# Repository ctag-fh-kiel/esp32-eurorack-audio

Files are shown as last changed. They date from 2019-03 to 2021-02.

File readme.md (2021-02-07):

# ESP32 Eurorack Audio Synthesis Module
Hardware for Strämpler

## What it is
Base board (design with KiCad) for using the ESP32 WROVER module in the context of real-time audio applications for eurorack synthesizer setups.

## Errata
CV in 1+2 are -1.5V .. 5.5V

## License
Licensed under CC BY-NC-SA 4.0
https://creativecommons.org/licenses/by-nc-sa/4.0/
(C) Robert Manzke 2019

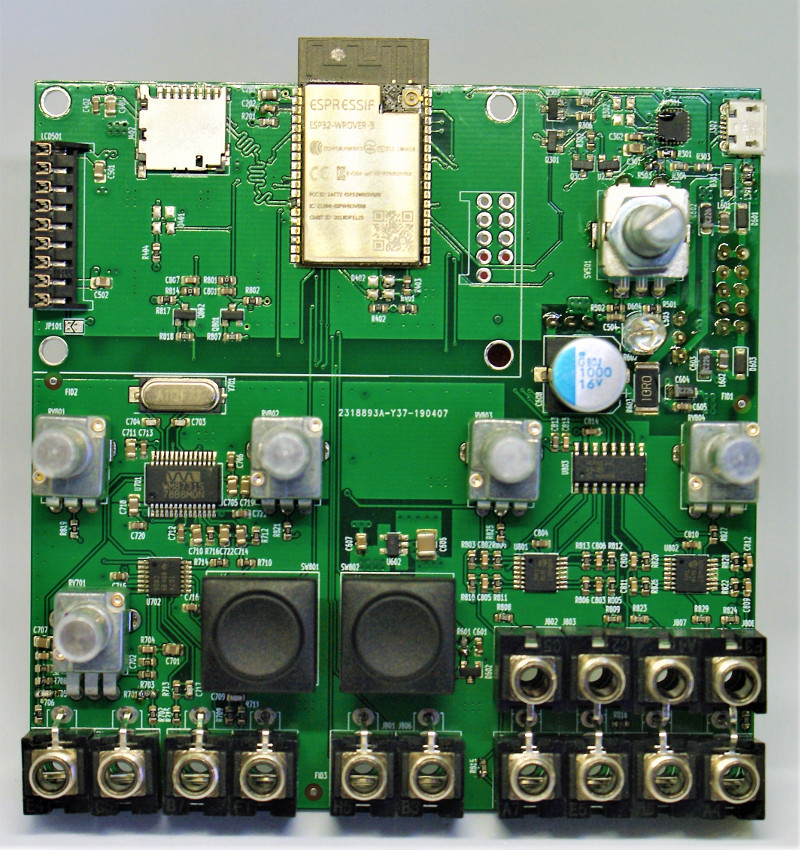
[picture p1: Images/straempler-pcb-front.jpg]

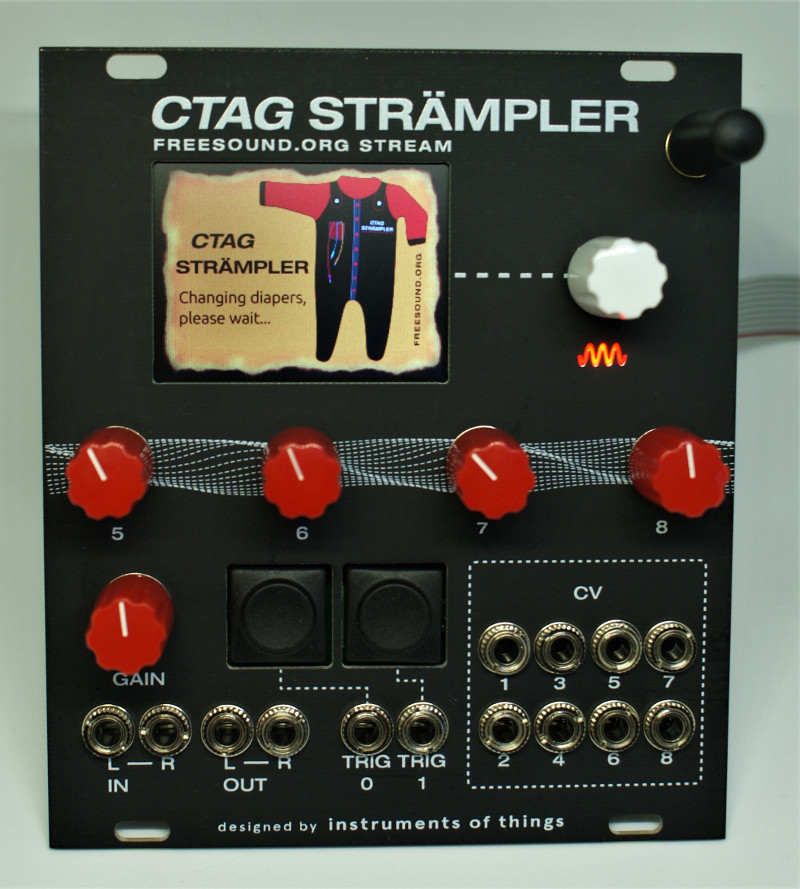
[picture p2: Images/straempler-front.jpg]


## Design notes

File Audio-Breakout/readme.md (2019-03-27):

# Stereo line IO + headphones breakout board for ESP32 Eurorack Audio Synthesis Module

Licensed under CC BY-NC-SA 4.0
https://creativecommons.org/licenses/by-nc-sa/4.0/
(C) Robert Manzke 2019

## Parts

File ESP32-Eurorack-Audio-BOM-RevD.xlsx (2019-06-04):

Designator | Package | Quantity | Designation | Mouser | Remarks
LCD501 | TFT_2.2 | 1 | TFT_ILI9341 | MDF7-9S-2.54DSA(55) |  | https://www.aliexpress.com/item/Smart-Electronics-2-2-Inch-240-320-Dots-SPI-TFT-LCD-Serial-Port-Module-Display-ILI9341/32607741715.html
C505,C504,C503,C813,C302,C402,C601,C605,C706,C712,C715,C716,C720,C721,C801,C804,C807,C810,C713 | C_0603_1608Metric | 19 | 100n | 81-GRM033C71C104KE4J (https://www.mouser.de/ProductDetail/Murata-Electronics/GRM033C71C104KE14J)
U301 | QFN-24-1EP_4x4mm_P0.5mm_EP2.6x2.6mm | 1 | CP2102N-A01-GQFN24 | 634-CP2102NA01GQFN24
D604 | LED_D5.0mm_Clear | 1 | ~ | 743-INL-5AR30 (https://www.mouser.de/QuickViewProdDetail.aspx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) |  | Larger angle and intensity: | 941-C5SMFRJECT0W0BB2
U202 | SOT-23 | 1 | MIC803 | 998-MIC803-31D3VM3TR
U601 | SIP3_11.6x8.5mm | 1 | R-78E3.3-1.0 | 919-R-78E3.3-1.0
R603 | R_2512_6332Metric | 1 | 10 | 279-CRGP2512F10R
C608 | CP_Elec_10x12.6 | 1 | 1000u | 661-APXG160A102MJA0G
C815,C202,C814 | C_0603_1608Metric | 3 | 1u | 603-CC603KRX7R7BB105 | X7R
U201 | ESP32-WROVER | 1 | ESP32-WROVER | 356-ESP32WROIB(16MB) |  | Important use WROVER-B the non-B has boot issues |  |  | For IPEX use e.g. this antenna | https://de.aliexpress.com/item/1pcs-2-4Ghz-Antenna-SMA-male-3dbi-Zigbee-wifi-antenna-mini-short-rubber-aerial-SMA/32813612333.html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
C201,C401,C501,C607,C701,C705,C707,C710,C714,C718,C719,C722,C502,C301,C711 | C_0805_2012Metric | 15 | 10u | 81-GRM21BR70J106KA3L (https://www.mouser.de/ProductDetail/Murata-Electronics/GRM21BR70J106KA73L) | X7R
C602,C603,C604 | CP_EIA-3216-12_Kemet-S | 3 | 22u | 647-F931C226MAA (https://www.mouser.de/ProductDetail/AVX/F951C226KQAAQ2)
C702,C708 | C_0603_1608Metric | 2 | 220p | 710-885012206055 (https://www.mouser.de/ProductDetail/Wurth-Electronics/885012206055)
C703,C704,C709,C717 | C_0603_1608Metric | 4 | 18p | 80-C0603C180J5G
C802,C803,C805,C806,C808,C809,C811,C812 | C_0603_1608Metric | 8 | 1n | 77-VJ0603Y102KXQCBC (https://www.mouser.de/ProductDetail/Vishay-Vitramon/VJ0603Y102KXQCW1BC)
D601,D603 | D_SOD-123 | 2 | STPS2L40ZFY | 511-STPS2L40ZFY
D602 | SOT-23 | 1 | LM4040B-10 | 595-LM4040B10IDBZR (https://www.mouser.de/ProductDetail/Texas-Instruments/LM4040B10IDBZR)
J302 | USB_Micro-B_Molex-105017-0001 | 1 | USB_B_Micro | 105017-0001 (https://www.mouser.de/ProductDetail/Molex/105017-0001)
J402 | microSD_HC_Hirose_DM3D-SF | 1 | Micro_SD_Card | 798-DM3D-SF (https://www.mouser.de/ProductDetail/Hirose-Connector/DM3D-SF)
J601 | PinHeader_2x05_P2.54mm_Vertical | 1 | PWR |  | Standard 2,54mm
J702 | THONKICONN | 1 | RIN |  | PJ398SM | https://www.thonk.co.uk/shop/thonkiconn/
J703 | THONKICONN | 1 | LIN/MONO |  | PJ398SM | https://www.thonk.co.uk/shop/thonkiconn/
J704 | THONKICONN | 1 | ROUT |  | PJ398SM | https://www.thonk.co.uk/shop/thonkiconn/
J705 | THONKICONN | 1 | LOUT |  | PJ398SM | https://www.thonk.co.uk/shop/thonkiconn/
J801 | THONKICONN | 1 | TRG0 |  | PJ398SM | https://www.thonk.co.uk/shop/thonkiconn/
J802 | THONKICONN | 1 | CVIN1 |  | PJ398SM | https://www.thonk.co.uk/shop/thonkiconn/
J803 | THONKICONN | 1 | CVIN3 |  | PJ398SM | https://www.thonk.co.uk/shop/thonkiconn/
J804 | THONKICONN | 1 | CVIN2 |  | PJ398SM | https://www.thonk.co.uk/shop/thonkiconn/
J805,J807 | THONKICONN | 2 | CVIN4 |  | PJ398SM | https://www.thonk.co.uk/shop/thonkiconn/
J806 | THONKICONN | 1 | TRG1 |  | PJ398SM | https://www.thonk.co.uk/shop/thonkiconn/
J808 | THONKICONN | 1 | CVIN5 |  | PJ398SM | https://www.thonk.co.uk/shop/thonkiconn/
J809 | THONKICONN | 1 | CVIN6 |  | PJ398SM | https://www.thonk.co.uk/shop/thonkiconn/
J810 | THONKICONN | 1 | CVIN7 |  | PJ398SM | https://www.thonk.co.uk/shop/thonkiconn/
L601,L602 | C_0805_2012Metric | 2 | 600 | 623-2508056017Y2
Q301,Q302,Q303,Q801,Q802 | SOT-23 | 5 | SS8050-G | 750-SS8050-G
RV701 | Alpha_9mm_stereo | 1 | 50k audio |  | VERTICAL - DUAL GANG/STEREO: A50K - 50K Audio | https://www.thonk.co.uk/shop/alpha-9mm-pots/
RV801,RV802,RV803,RV804 | Alpha_9mm | 4 | 10k lin |  | VERTICAL: B10K - 10K Linear | https://www.thonk.co.uk/shop/thonkiconn/
SW501 | RotaryEncoder_Alps_EC11E-Switch_Vertical_H20mm | 1 | SEL |  |  | https://www.aliexpress.com/item/10pcs-Rotary-encoder-code-switch-EC11-audio-digital-potentiometer-with-switch-5Pin-handle-length-20mm-WAVGAT/32839106848.html
SW801 | SW_6425 | 1 | TRG0 | 979-6425.0101 | Cap | 979-826.000.071 | Or black | 826000011
SW802 | SW_6425 | 1 | TRG1 | 979-6425.0101 | Cap | 979-826.000.071 |  | 826000011
U602 | TSOT-23-5 | 1 | ADP7118 | 584-ADP7118AUJZ3.3R7
U701 | SSOP-28_5.3x10.2mm_P0.65mm | 1 | WM8731 | 238-WM8731SEDS/V (https://www.mouser.de/ProductDetail/Cirrus-Logic/WM8731SEDS-V?qs=sGAEpiMZZMthNezIpKscMWquczdXLZMI)
U702 | TSSOP-14_4.4x5mm_P0.65mm | 1 | TL074 | 595-TL074CPWR (https://www.mouser.de/ProductDetail/Texas-Instruments/TL074CPWR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)
U801,U802 | TSSOP-14_4.4x5mm_P0.65mm | 2 | MCP6004 | 579-MCP6004-I/ST (https://www.mouser.de/ProductDetail/Microchip-Technology/MCP6004-I-ST)
U803 | SOIC-16_3.9x9.9mm_P1.27mm | 1 | MCP3208 | 579-MCP3208T-CI/SL (https://www.mouser.de/ProductDetail/Microchip-Technology/MCP3208T-CI-SL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)
Y701 | Crystal_SMD_HC49-SD | 1 | 11.289600MHz | 815-ABLS211.2896B4YT (https://www.mouser.de/ProductDetail/ABRACON/ABLS2-112896MHz-B4Y-T)
R201,R301,R305,R306,R401,R402,R403,R404,R501,R502,R503,R802,R817,R302 | R_0603_1608Metric | 14 | 10k | 652-CR0603FX-1002ELF | 1%
R303 | R_0603_1608Metric | 1 | 22.1k | 652-CR0603FX-2212ELF (https://www.mouser.de/ProductDetail/Bourns/CR0603-FX-2212ELF) | 1%
R304 | R_0603_1608Metric | 1 | 47.5k | 603-RC0603FR-0747K5L (https://www.mouser.de/ProductDetail/Yageo/RC0603FR-0747K5L) | 1%
R601 | R_0603_1608Metric | 1 | 220 | 652-CR0603FX-2200ELF | 1%
R602 | R_0805_2012Metric | 1 | 68 | 603-AC0603FR-0768RL | 1%
R701,R705 | R_0603_1608Metric | 2 | 3k3 | 652-CR0603-FX3301ELF | 1%
R702,R706 | R_0603_1608Metric | 2 | 22k | 652-CR0603FX-2202ELF | 1%
R703,R704,R707,R708,R710,R714 | R_0603_1608Metric | 6 | 5k6 | 652-CR0603FX-5601ELF | 1%
R709,R712,R713,R716 | R_0603_1608Metric | 4 | 39k | 652-CR0603FX-3902ELF | 1%
R711,R715 | R_0603_1608Metric | 2 | 1k | 652-CR0603FX-1001ELF | 1%
R803,R810 | R_0603_1608Metric | 2 | 180k | 652-CR0603FX-1803ELF | 1%
R804,R811 | R_0603_1608Metric | 2 | 47k | 652-CR0603FX-4702ELF (https://www.mouser.de/ProductDetail/Bourns/CR0603-FX-4702ELF) | 1%
R805,R812,R819,R821,R825,R827 | R_0603_1608Metric | 6 | 200k | 652-CR0603FX-2003ELF | 1%
R806,R813 | R_0603_1608Metric | 2 | 33k | 652-CR0603FX-3302ELF | 1%
R807,R808,R809,R815,R816,R818,R823,R824,R829,R830 | R_0603_1608Metric | 10 | 100k | 603-RC0603FR-07100KL (https://www.mouser.de/ProductDetail/Yageo/RC0603FR-07100KL) | 1%
R820,R822,R826,R828 | R_0603_1608Metric | 4 | 66.5k | 652-CR0603-FX6652ELF | 1%
J701 | PinHeader_2x05_P2.54mm_Vertical_SMD | 1 | AUEXT |  | Standard 2,54mm SMD
C606 | C_1210_3225Metric | 1 | 10u | 710-885012209005 | X7R 16V
TP101 | TestPoint_Keystone_5019_Minature | 1 | TP_IO19 | 534-5019

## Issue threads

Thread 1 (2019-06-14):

R704 und C702 designators swapped in top silkscreen rev-c2

ctag-fh-kiel, 2019-06-14:
Fixed in rev-d

Closed 2019-06-14.

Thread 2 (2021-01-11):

What kind of esp32-wrover specific in this project?

colesnicov, 2021-01-11:
Good day. I want to ask **what kind of esp32-wrover specific in this project**? There are a lot of them, and I don't know much about them, so I don't want to make a mistake, I'd rather ask. **Which ones are guaranteed to work for me here?** [Here (_mouser_)](https://eu.mouser.com/Search/Refine?Keyword=ESP32-WROVER) I found **esp32-wrover**, **esp32-wrover-e**, **esp32-wrover-i**, **esp32-wrover-ie**, **esp32-wrover-b**, **esp32-wrover-ib**... Thank you for your help.

ctag-fh-kiel, 2021-01-11:
You need a wrover with 16MB flash and at least 4 MB SPI RAM, it depends if you want external antenna, if so, chose WROVER with IPEX connector.
Component details are here https://github.com/ctag-fh-kiel/ctag-tbd/tree/master/hw/pcb in the bom.xlsx spreadsheet.
esp32-wrover-ie is the newest one, should work well too. In the bom is esp32-wrover-ib

colesnicov, 2021-01-12:
Thank you.

colesnicov, 2021-01-12:
Hi. I'm sorry, but I'm here again. I'm looking at the BOM file you wrote me the link above, and at the same time I have a project open in the kicad from the address https://github.com/ctag-fh-kiel/esp32-eurorack-audio. And I see here that the components that are listed in the BOM file are missing here in the project. Can you please explain to me which project it is, sw, hw, bom? It seems to me you have it scattered over different folders + duplication..  :-/

**It should be stated in the BOM: C508, C507, C503, C506, C505 = 4.7uF but in the project C505 = 100nF (not 4.7uF !!) and C503, C506, C507, C508 are missing** in the project. It can't work like this ..

colesnicov, 2021-01-12:
Or one more time. These are two different projects, but do they use the same esp32-wrover module? HMM, I'm confused. Correctly?

colesnicov, 2021-01-12:
I've got it. I'm sorry :)

ctag-fh-kiel, 2021-01-12:
No problem ;) The project is pretty well structured. Everything regarding hardware is in the hw folder. All other folders are relevant for SW (firmware + simulator).
hw/frontplate are gerbers for a frontplate design.
hw/pcb are all KiCad and gerbers for the hardware.
Note that the current design uses QFNs + 0402s which are very advanced for handsoldering.
Let me know if you spot any errors in the bom.xlsx file, I will try to fix and am grateful for help sorting out issues.

colesnicov, 2021-01-12:
No no, we probably don't understand each other. I want to build for a friend [this CTAG Strämpler](https://github.com/ctag-fh-kiel/ctag-straempler)

I went through your repository and I understood it like this:
https://github.com/ctag-fh-kiel/esp32-eurorack-audio is hardware
https://github.com/ctag-fh-kiel/ctag-straempler is software
https://github.com/ctag-fh-kiel/ctag-tbd is something else (add-on module) ...

It's right?

ctag-fh-kiel, 2021-01-12:
Ah, got you, sorry, I was at the TBD ;)
Yes, you are right! Sorry for the confusion.
Forget my previous comment...

ctag-fh-kiel, 2021-01-12:
BOM is here https://github.com/ctag-fh-kiel/esp32-eurorack-audio/blob/rev-d/ESP32-Eurorack-Audio-BOM-RevD.xlsx

colesnicov, 2021-01-12:
No problem. Thank you for your help ;)

colesnicov, 2021-01-13:
Hi. I'm bothering again :) I can't opt for some of the ESP32-wrover module. There is a note in the BOM file that I have to use 'WROVER-B' otherwise non-B has problems booting. Could you please tell me which of the modules I should buy here is the [link to the mouser](https://cz.mouser.com/Espressif/WiFi-Modules-80211/ESP32-WROVER-Series/_/N-1y98oj6Z6l7qaZ1y94wm8)? I did not find a version with 16 MB but there are others. I'm a dick. I don't work much with ESP, so I can't decide.

ctag-fh-kiel, 2021-01-13:
You can use this one ESP32-WROVER-IE, ESP32-D0WD-V3, 3.3V 64Mbit PSRAM, 16 MB SPI flash, IPEX connector:
https://www.mouser.de/ProductDetail/Espressif-Systems/ESP32-WROVER-IEM213EH2864UH3Q0/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

colesnicov, 2021-01-14:
OK. I'll try. Thank you for the recommendation.

Closed 2021-01-12.

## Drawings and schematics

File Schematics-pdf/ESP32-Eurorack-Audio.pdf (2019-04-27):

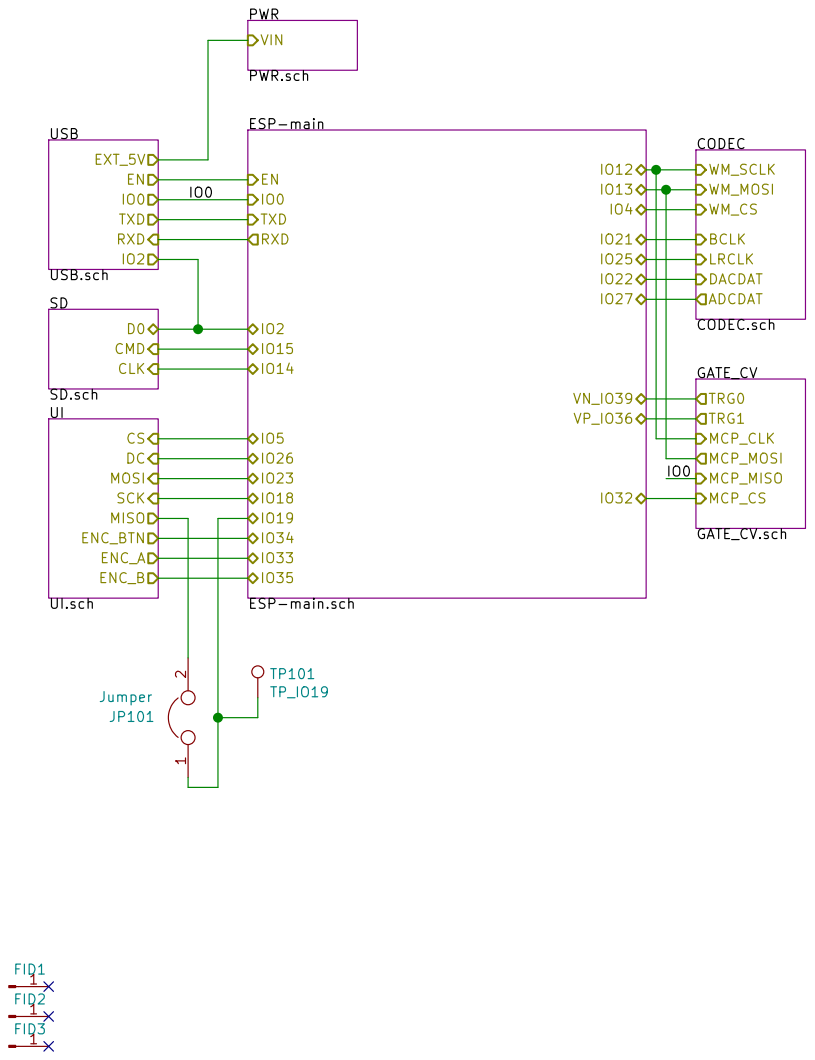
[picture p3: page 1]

PWR
PWR.sch VIN
ESP-main ESP-main.sch TXD

https://creativecommons.org/licenses/by-nc-sa/4.0/ Licensed under CC BY-NC-SA 4.0

File: ESP32-Eurorack-Audio.sch Sheet: / (c) Robert Manzke 2019

Id: 1/8 Title: ESP32 Eurorack Audio Module

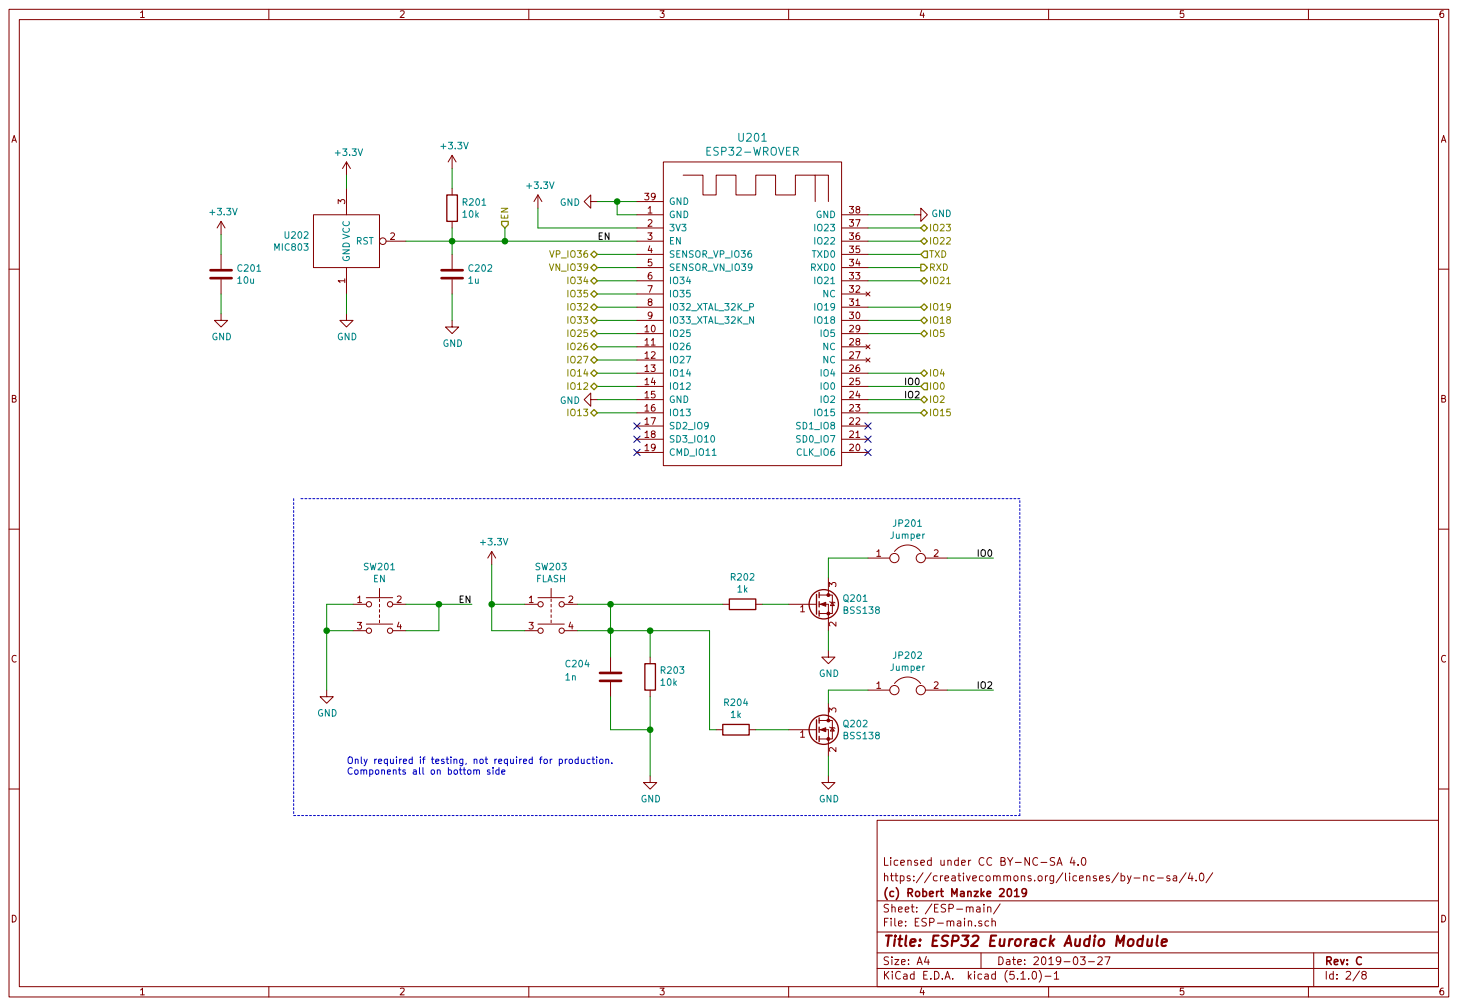
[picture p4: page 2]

+3.3V GND
Components all on bottom side GND
1u GND

Only required if testing, not required for production.

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

File: ESP-main.sch Sheet: /ESP-main/ (c) Robert Manzke 2019

Id: 2/8 Title: ESP32 Eurorack Audio Module

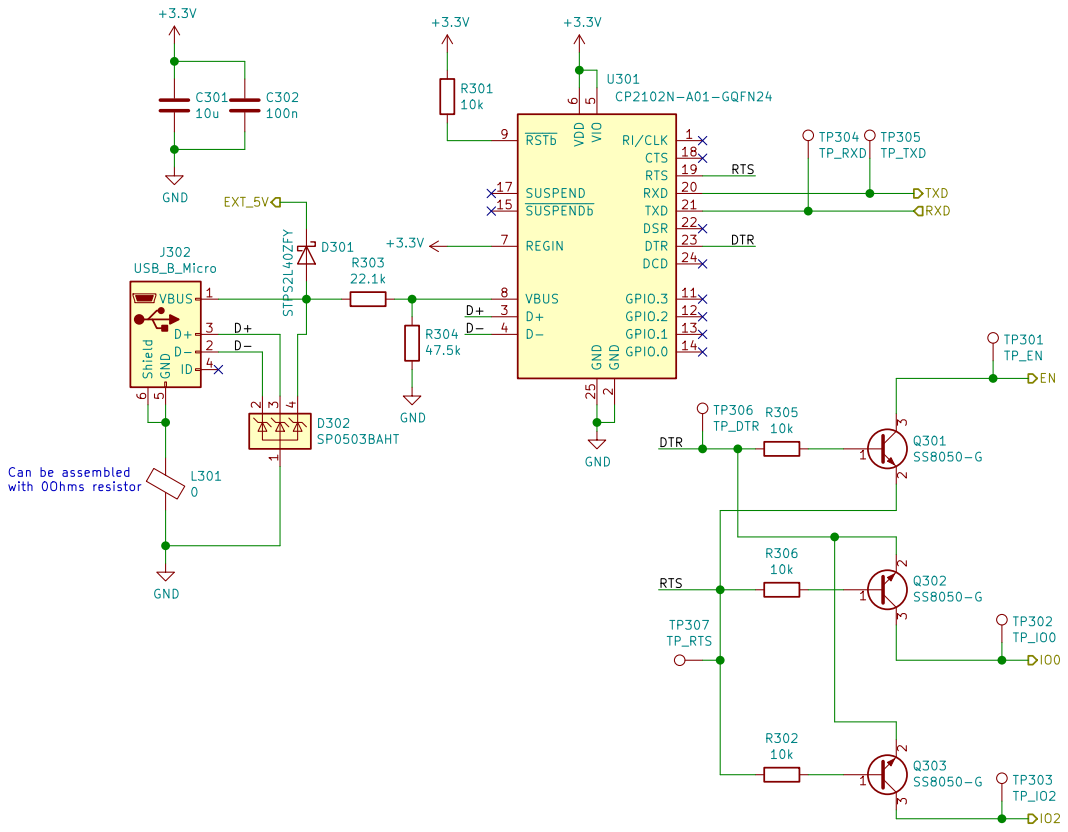
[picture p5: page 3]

2 RXD 20 TXD 21 DSR 22 DTR 23 DCD 24 GND 25 D+ 3 D- 4 VIO

Can be assembled with 0Ohms resistor

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

File: USB.sch Sheet: /USB/ (c) Robert Manzke 2019

Id: 3/8 Title: ESP32 Eurorack Audio Module

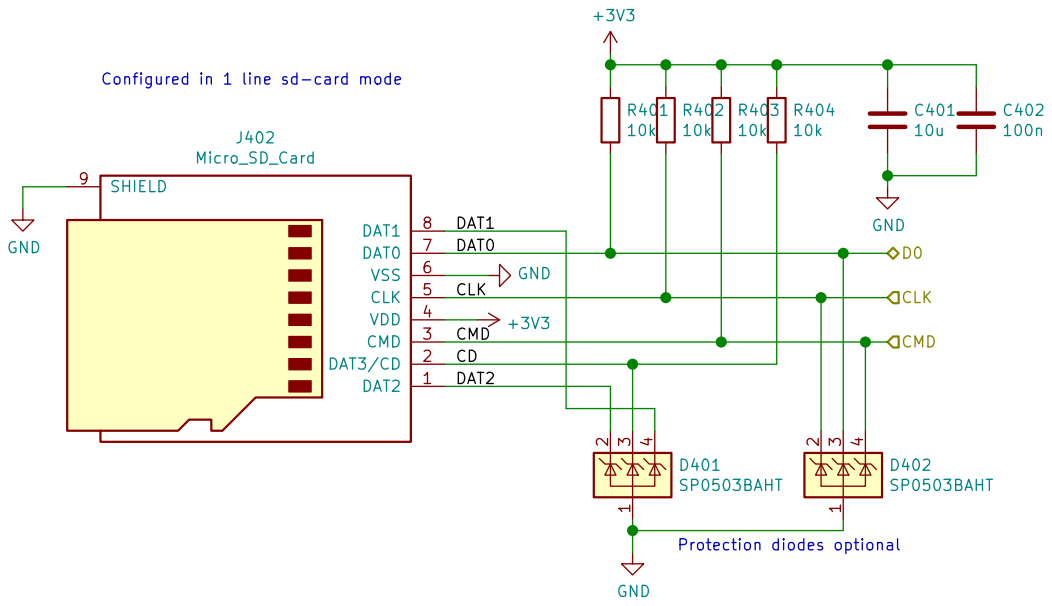
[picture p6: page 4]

DAT2 Configured in 1 line sd-card mode

+3V3 GND

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

File: SD.sch Sheet: /SD/ (c) Robert Manzke 2019

Id: 4/8 Title: ESP32 Eurorack Audio Module

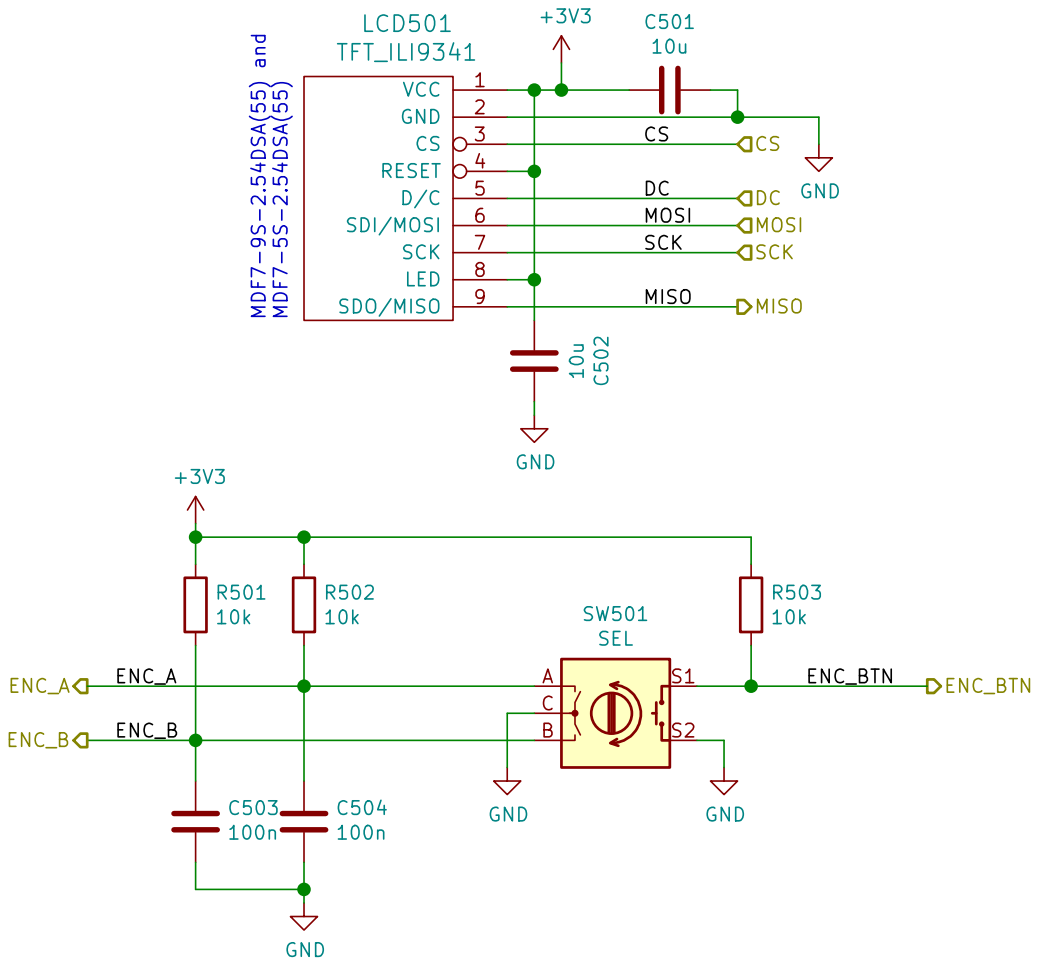
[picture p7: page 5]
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

File: UI.sch Sheet: /UI/ (c) Robert Manzke 2019

Id: 5/8 Title: ESP32 Eurorack Audio Module

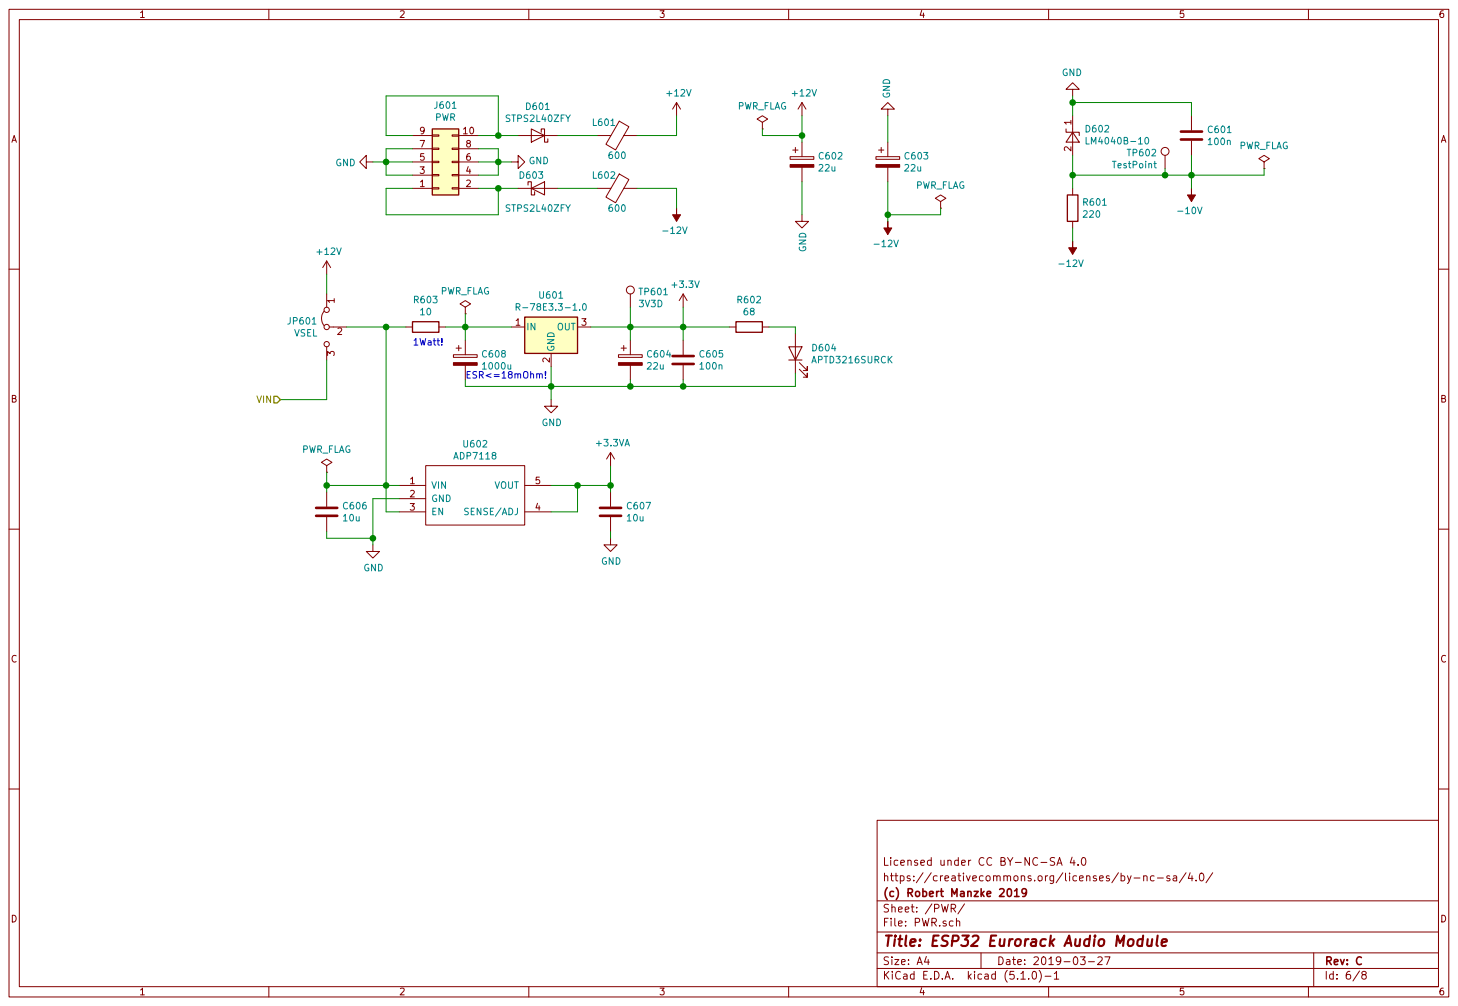
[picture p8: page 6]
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

File: PWR.sch Sheet: /PWR/ (c) Robert Manzke 2019

Id: 6/8 Title: ESP32 Eurorack Audio Module

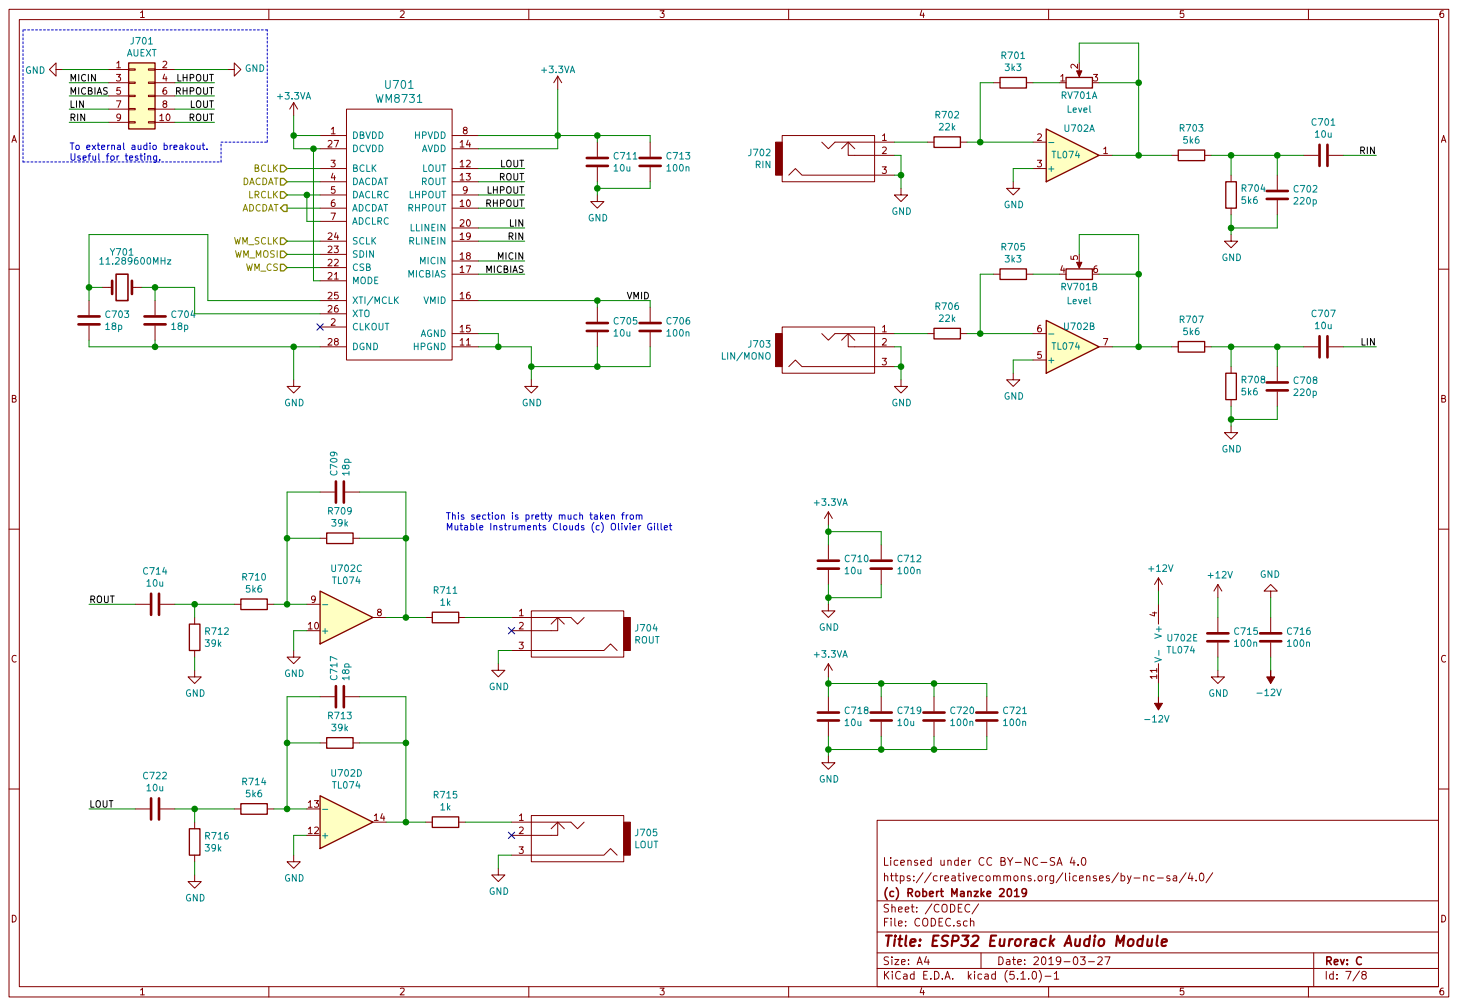
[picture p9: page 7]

Mutable Instruments Clouds (c) Olivier Gillet To external audio breakout. Useful for testing.

This section is pretty much taken from

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

File: CODEC.sch Sheet: /CODEC/ (c) Robert Manzke 2019

Id: 7/8 Title: ESP32 Eurorack Audio Module

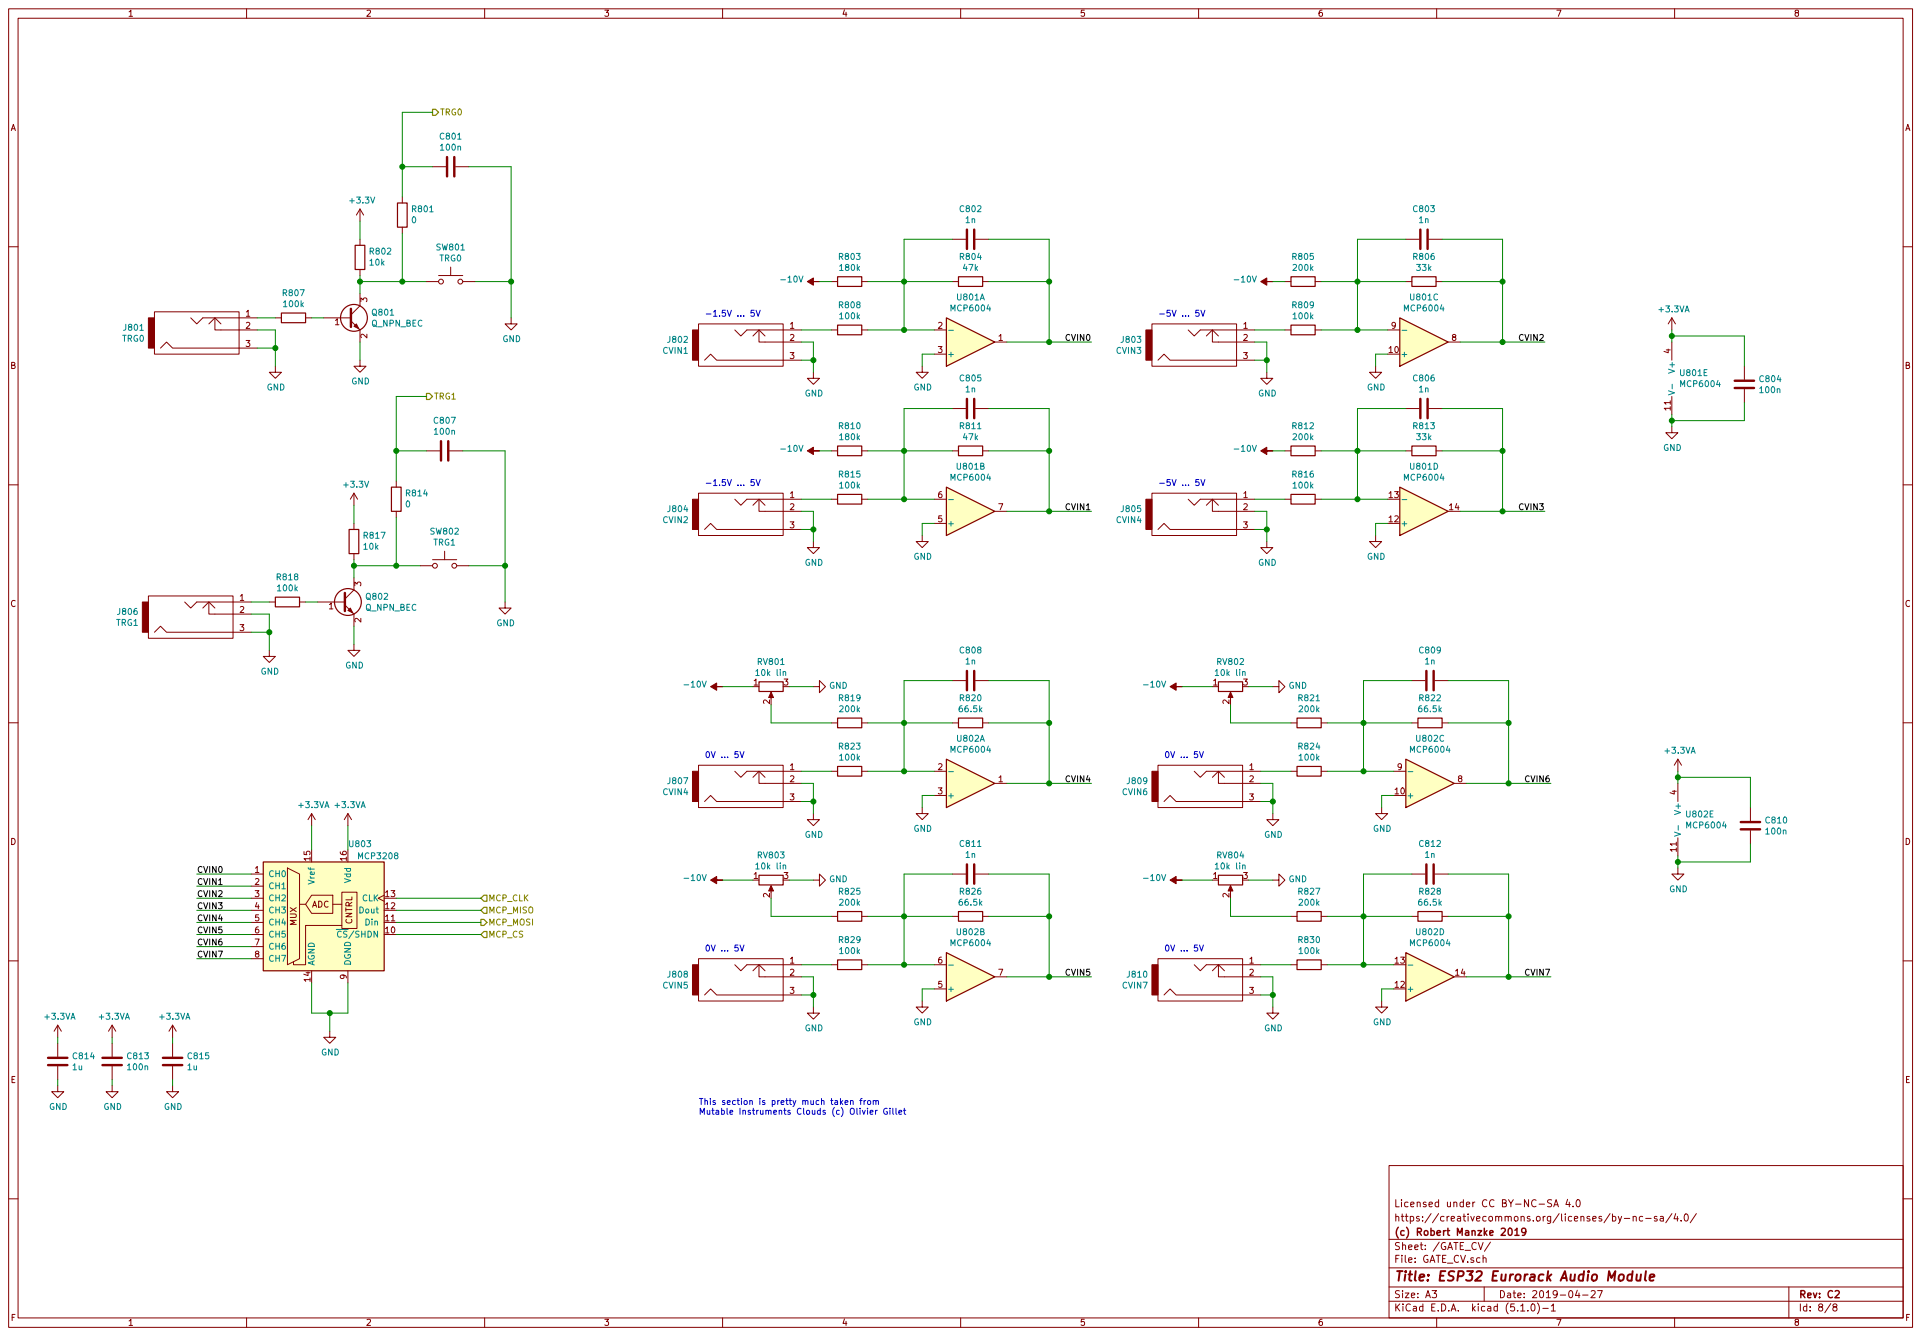
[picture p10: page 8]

This section is pretty much taken from
Mutable Instruments Clouds (c) Olivier Gillet

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

(c) Robert Manzke 2019
Sheet: /GATE_CV/
File: GATE_CV.sch
Id: 8/8 Title: ESP32 Eurorack Audio Module

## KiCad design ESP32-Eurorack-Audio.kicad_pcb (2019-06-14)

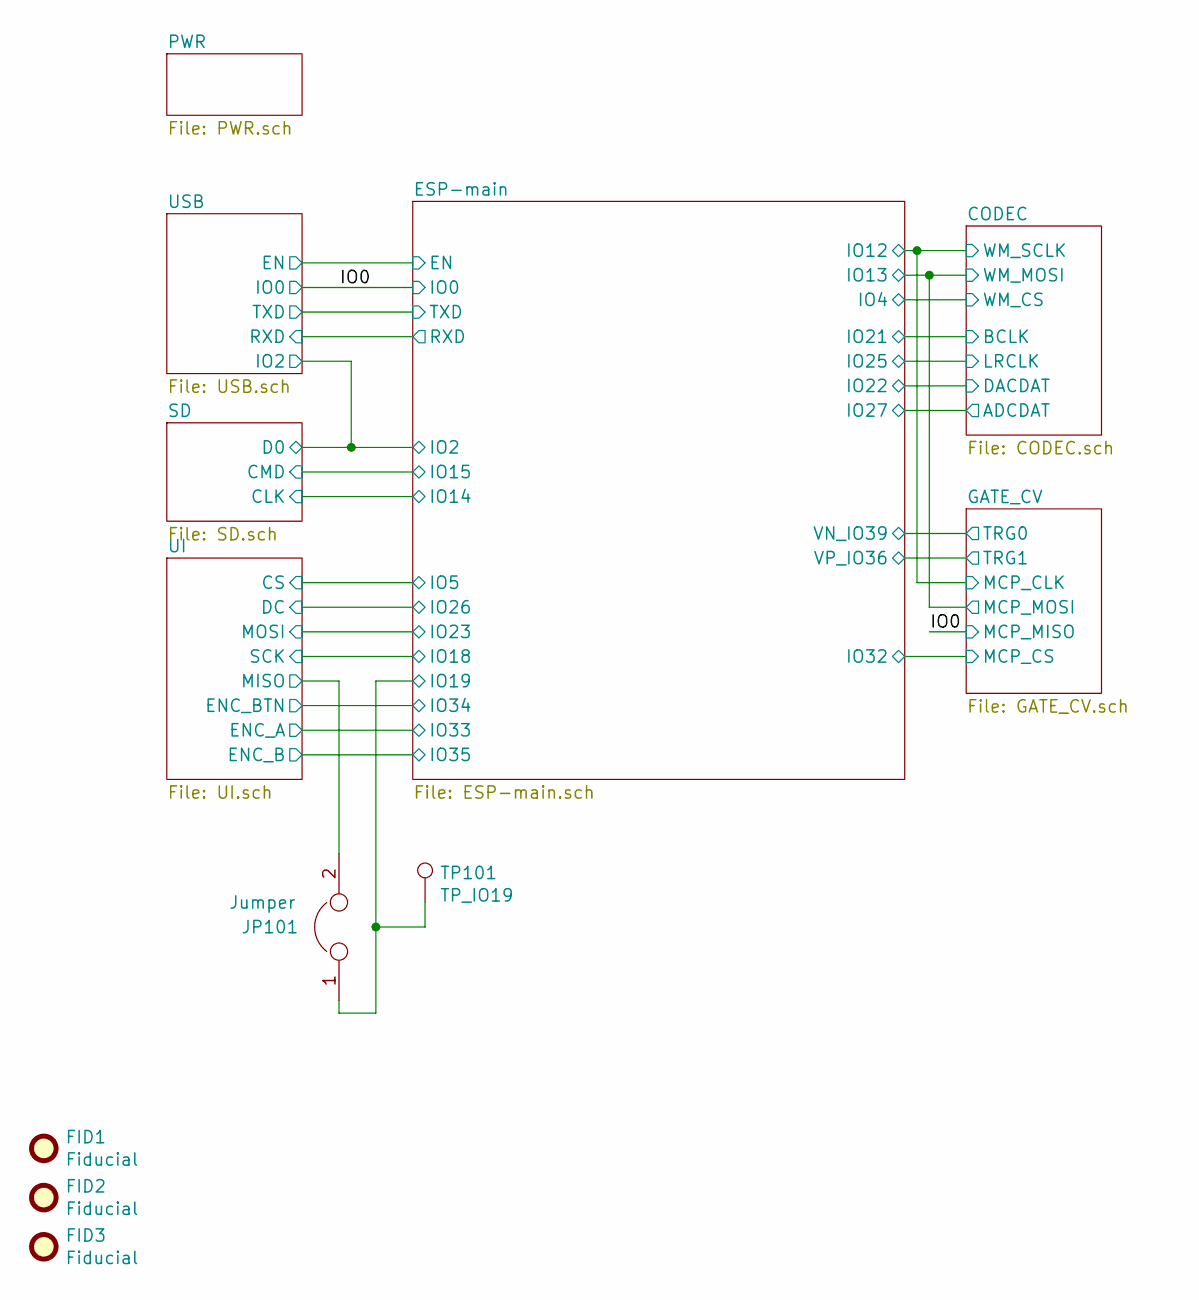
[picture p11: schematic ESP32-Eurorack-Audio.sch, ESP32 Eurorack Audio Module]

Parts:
FID1, FID2, FID3: Fiducial; Fiducial_1mm_Mask2mm
JP101: Jumper; SolderJumper-2_P1.3mm_Open_TrianglePad1.0x1.5mm
TP101: TP_IO19; TestPoint_Keystone_5019_Minature

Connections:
/ESP-main/IO19: JP101.1, TP101.1; also elsewhere on the board
/UI/MISO: JP101.2; also elsewhere on the board

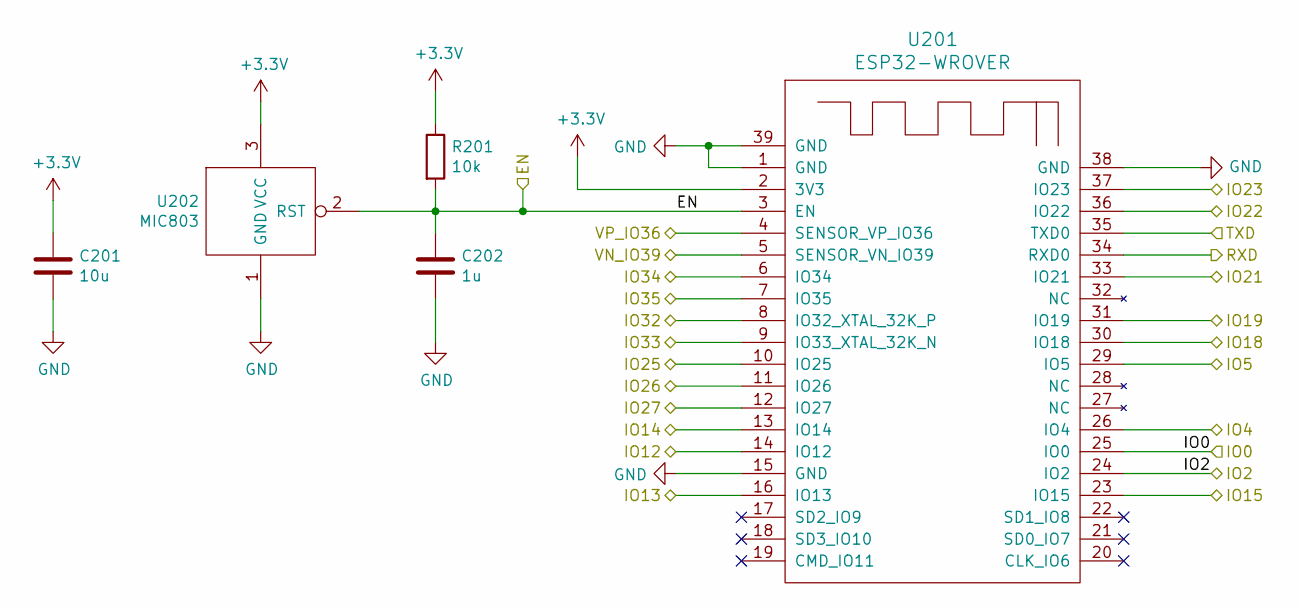
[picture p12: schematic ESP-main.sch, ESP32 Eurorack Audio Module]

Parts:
C201: 10u; C_0805_2012Metric
C202: 1u; C_0603_1608Metric
R201: 10k; R_0603_1608Metric
U201: ESP32-WROVER
U202: MIC803; SOT-23

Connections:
/CODEC/ADCDAT: U201.12 (IO27); also elsewhere on the board
/CODEC/BCLK: U201.33 (IO21); also elsewhere on the board
/CODEC/DACDAT: U201.36 (IO22); also elsewhere on the board
/ESP-main/EN: C202.1, R201.2, U201.3 (EN), U202.2 (RST); also elsewhere on the board
/ESP-main/IO4: U201.26 (IO4); also elsewhere on the board
/ESP-main/IO12: U201.14 (IO12); also elsewhere on the board
/ESP-main/IO13: U201.16 (IO13); also elsewhere on the board
/ESP-main/IO18: U201.30 (IO18); also elsewhere on the board
/ESP-main/IO19: U201.31 (IO19); also elsewhere on the board
/ESP-main/IO23: U201.37 (IO23); also elsewhere on the board
/ESP-main/IO25: U201.10 (IO25); also elsewhere on the board
/ESP-main/IO32: U201.8 (IO32_XTAL_32K_P); also elsewhere on the board
/ESP-main/RXD: U201.34 (RXD0); also elsewhere on the board
/ESP-main/TXD: U201.35 (TXD0); also elsewhere on the board
/GATE_CV/TRG0: U201.5 (SENSOR_VN_IO39); also elsewhere on the board
/GATE_CV/TRG1: U201.4 (SENSOR_VP_IO36); also elsewhere on the board
/IO0: U201.25 (IO0); also elsewhere on the board
/SD/CLK: U201.13 (IO14); also elsewhere on the board
/SD/CMD: U201.23 (IO15); also elsewhere on the board
/SD/D0: U201.24 (IO2); also elsewhere on the board
/UI/CS: U201.29 (IO5); also elsewhere on the board
/UI/DC: U201.11 (IO26); also elsewhere on the board
/UI/ENC_A: U201.9 (IO33_XTAL_32K_N); also elsewhere on the board
/UI/ENC_B: U201.7 (IO35); also elsewhere on the board
/UI/ENC_BTN: U201.6 (IO34); also elsewhere on the board
GND: C201.2, C202.2, U201.1 (GND), U201.15 (GND), U201.38 (GND), U201.39 (GND), U202.1 (GND); also elsewhere on the board

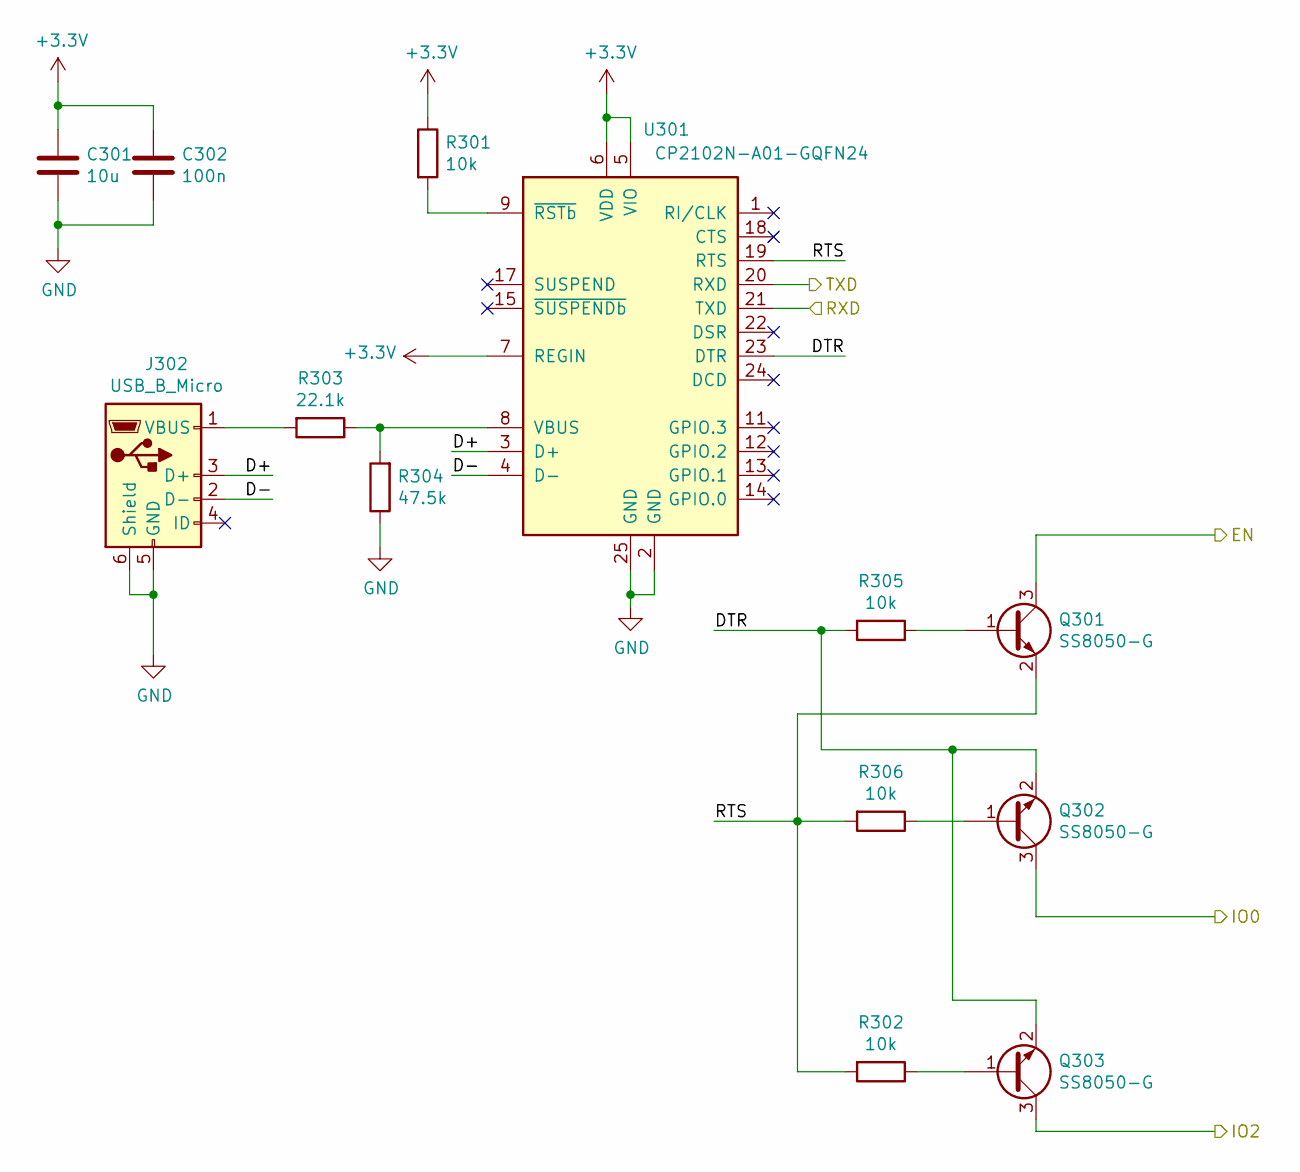
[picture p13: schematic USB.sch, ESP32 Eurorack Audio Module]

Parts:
C301: 10u; C_0805_2012Metric
C302: 100n; C_0603_1608Metric
J302: USB_B_Micro; USB_Micro-B_Molex-105017-0001
Q301, Q302, Q303: SS8050-G; SOT-23
R301, R302, R305, R306: 10k; R_0603_1608Metric
R303: 22.1k; R_0603_1608Metric
R304: 47.5k; R_0603_1608Metric
U301: CP2102N-A01-GQFN24; QFN-24-1EP_4x4mm_P0.5mm_EP2.6x2.6mm

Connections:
/ESP-main/EN: Q301.3 (C); also elsewhere on the board
/ESP-main/RXD: U301.21 (TXD); also elsewhere on the board
/ESP-main/TXD: U301.20 (RXD); also elsewhere on the board
/IO0: Q302.3 (C); also elsewhere on the board
/SD/D0: Q303.3 (C); also elsewhere on the board
/USB/D+: J302.3 (D+), U301.3 (D+)
/USB/D-: J302.2 (D-), U301.4 (D-)
/USB/DTR: Q302.2 (E), Q303.2 (E), R305.2, U301.23 (DTR)
/USB/RTS: Q301.2 (E), R302.2, R306.2, U301.19 (RTS)
GND: C301.2, C302.2, J302.5 (GND), J302.6 (Shield), R304.1, U301.2 (GND), U301.25 (GND); also elsewhere on the board
unnamed: J302.1 (VBUS), R303.2
unnamed: Q301.1 (B), R305.1
unnamed: Q302.1 (B), R306.1
unnamed: Q303.1 (B), R302.1
unnamed: R301.2, U301.9 (~RSTb)
unnamed: R303.1, R304.2, U301.8 (VBUS)

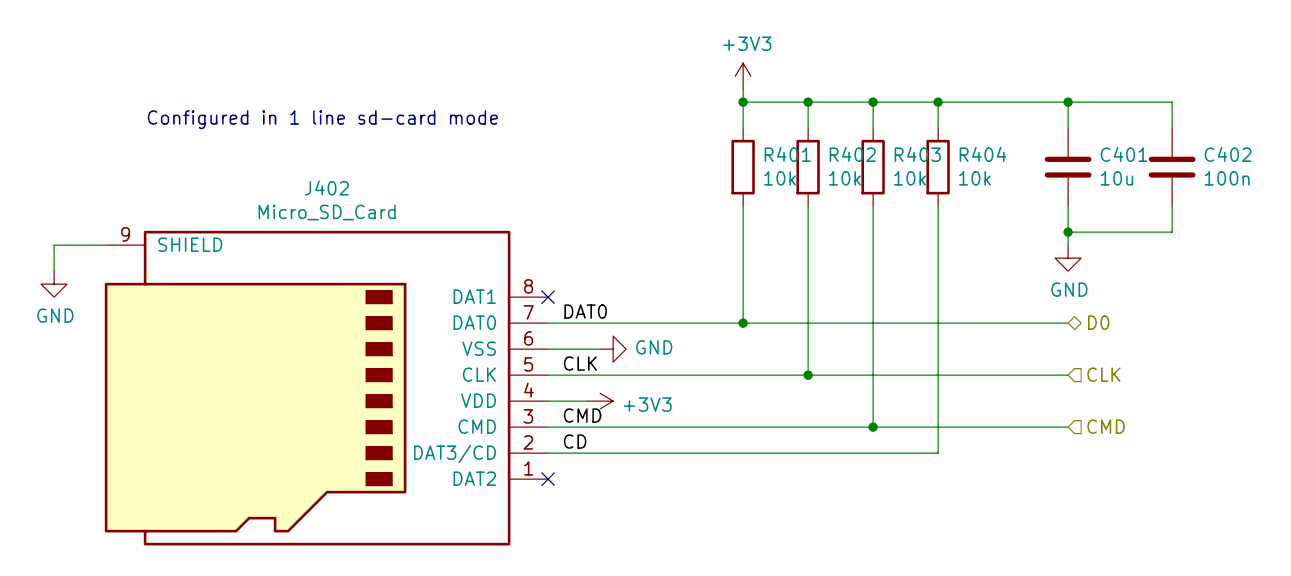
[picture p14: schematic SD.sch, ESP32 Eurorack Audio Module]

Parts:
C401: 10u; C_0805_2012Metric
C402: 100n; C_0603_1608Metric
J402: Micro_SD_Card; microSD_HC_Hirose_DM3D-SF
R401, R402, R403, R404: 10k; R_0603_1608Metric

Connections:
/SD/CD: J402.2 (DAT3/CD), R404.2
/SD/CLK: J402.5 (CLK), R402.2; also elsewhere on the board
/SD/CMD: J402.3 (CMD), R403.2; also elsewhere on the board
/SD/D0: J402.7 (DAT0), R401.2; also elsewhere on the board
GND: C401.2, C402.2, J402.6 (VSS), J402.9 (SHIELD); also elsewhere on the board

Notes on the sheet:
Configured in 1 line sd-card mode

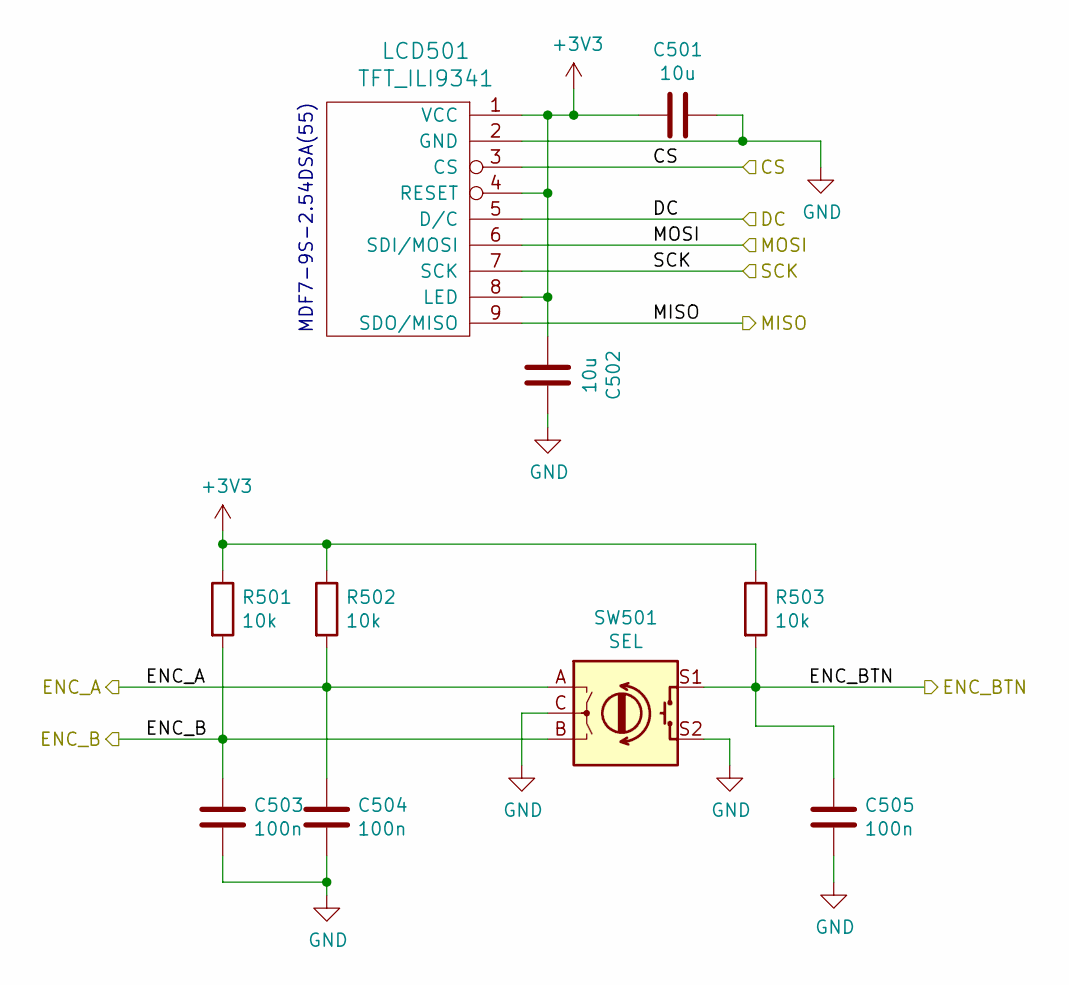
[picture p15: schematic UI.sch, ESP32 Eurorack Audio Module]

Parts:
C501, C502: 10u; C_0805_2012Metric
C503, C504, C505: 100n; C_0603_1608Metric
LCD501: TFT_ILI9341; TFT_2.2
R501, R502, R503: 10k; R_0603_1608Metric
SW501: SEL; RotaryEncoder_Alps_EC11E-Switch_Vertical_H20mm

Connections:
/ESP-main/IO18: LCD501.7 (SCK); also elsewhere on the board
/ESP-main/IO23: LCD501.6 (SDI/MOSI); also elsewhere on the board
/UI/CS: LCD501.3 (CS); also elsewhere on the board
/UI/DC: LCD501.5 (D/C); also elsewhere on the board
/UI/ENC_A: C504.2, R502.2, SW501.A; also elsewhere on the board
/UI/ENC_B: C503.2, R501.2, SW501.B; also elsewhere on the board
/UI/ENC_BTN: C505.2, R503.2, SW501.S1; also elsewhere on the board
/UI/MISO: LCD501.9 (SDO/MISO); also elsewhere on the board
GND: C501.1, C502.1, C503.1, C504.1, C505.1, LCD501.2 (GND), SW501.C, SW501.S2; also elsewhere on the board

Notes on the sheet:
MDF7-9S-2.54DSA(55)

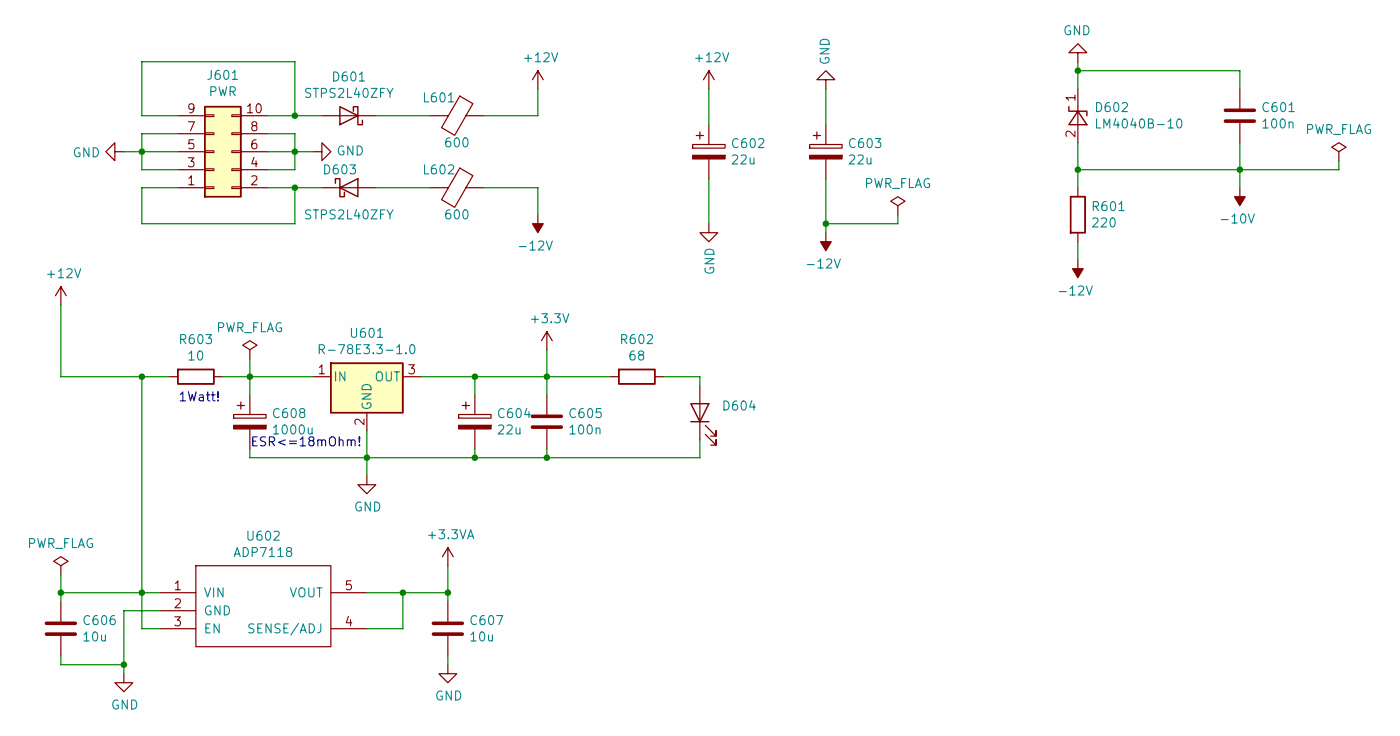
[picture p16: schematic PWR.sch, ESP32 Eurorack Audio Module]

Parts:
C601, C605: 100n; C_0603_1608Metric
C602, C603, C604: 22u; CP_EIA-3216-12_Kemet-S
C606: 10u; C_1210_3225Metric
C607: 10u; C_0805_2012Metric
C608: 1000u; CP_Elec_10x12.6
D601, D603: STPS2L40ZFY; D_SOD-123
D602: LM4040B-10; SOT-23
D604: LED_D5.0mm_Clear
J601: PWR; PinHeader_2x05_P2.54mm_Vertical
L601, L602: 600; C_0805_2012Metric
R601: 220; R_0603_1608Metric
R602: 68; R_0805_2012Metric
R603: 10; R_2512_6332Metric
U601: R-78E3.3-1.0; SIP3_11.6x8.5mm
U602: ADP7118; TSOT-23-5

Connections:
+3.3VA: C607.1, U602.4 (SENSE/ADJ), U602.5 (VOUT); also elsewhere on the board
+12V: C602.1, C606.1, L601.1, R603.2, U602.1 (VIN), U602.3 (EN); also elsewhere on the board
-10V: C601.2, D602.2 (A), R601.1; also elsewhere on the board
-12V: C603.2, L602.1, R601.2; also elsewhere on the board
GND: C601.1, C602.2, C603.1, C604.2, C605.2, C606.2, C607.2, C608.2, D602.1 (K), D604.1 (K), J601.3, J601.4, J601.5, J601.6, J601.7, J601.8, U601.2 (GND), U602.2 (GND); also elsewhere on the board
unnamed: C608.1, R603.1, U601.1 (IN)
unnamed: D601.1 (K), L601.2
unnamed: D601.2 (A), J601.9, J601.10
unnamed: D603.1 (K), J601.1, J601.2
unnamed: D603.2 (A), L602.2
unnamed: D604.2 (A), R602.1

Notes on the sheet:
ESR<=18mOhm!
1Watt!

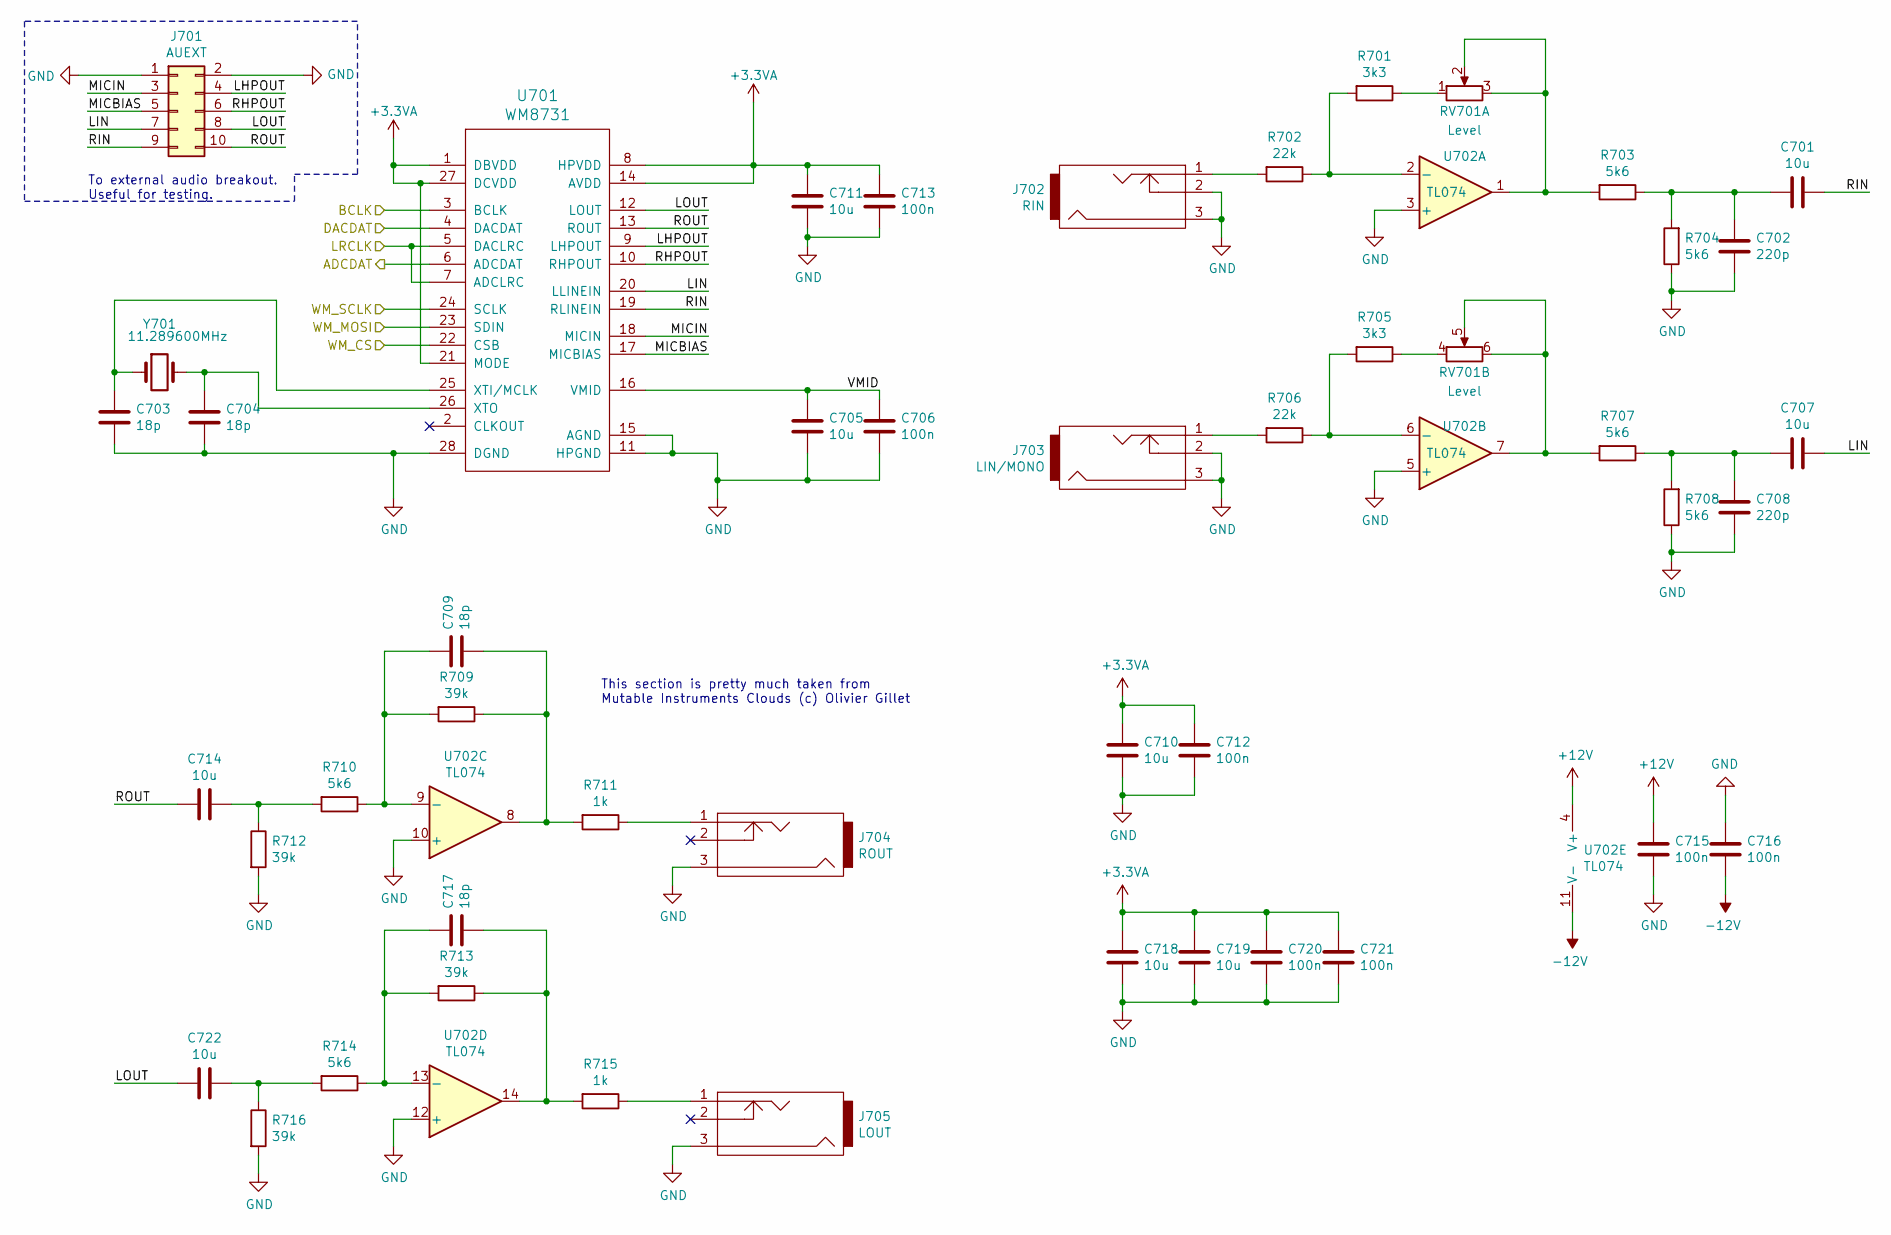
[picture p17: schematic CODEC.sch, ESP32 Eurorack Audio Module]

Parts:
C701, C705, C707, C710, C711, C714, C718, C719, C722: 10u; C_0805_2012Metric
C702, C708: 220p; C_0603_1608Metric
C703, C704, C709, C717: 18p; C_0603_1608Metric
C706, C712, C713, C715, C716, C720, C721: 100n; C_0603_1608Metric
J701: AUEXT; PinHeader_2x05_P2.54mm_Vertical_SMD
J702: RIN; THONKICONN
J703: LIN/MONO; THONKICONN
J704: ROUT; THONKICONN
J705: LOUT; THONKICONN
R701, R705: 3k3; R_0603_1608Metric
R702, R706: 22k; R_0603_1608Metric
R703, R704, R707, R708, R710, R714: 5k6; R_0603_1608Metric
R709, R712, R713, R716: 39k; R_0603_1608Metric
R711, R715: 1k; R_0603_1608Metric
RV701: Level; Alpha_9mm_stereo
U701: WM8731; SSOP-28_5.3x10.2mm_P0.65mm
U702: TL074; TSSOP-14_4.4x5mm_P0.65mm
Y701: 11.289600MHz; Crystal_SMD_HC49-SD

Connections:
+3.3VA: C710.1, C711.1, C712.1, C713.1, C718.1, C719.1, C720.1, C721.1, U701.1 (DBVDD), U701.8 (HPVDD), U701.14 (AVDD), U701.21 (MODE), U701.27 (DCVDD); also elsewhere on the board
+12V: C715.1, U702.4 (V+); also elsewhere on the board
-12V: C716.2, U702.11 (V-); also elsewhere on the board
/CODEC/ADCDAT: U701.6 (ADCDAT); also elsewhere on the board
/CODEC/BCLK: U701.3 (BCLK); also elsewhere on the board
/CODEC/DACDAT: U701.4 (DACDAT); also elsewhere on the board
/CODEC/LHPOUT: J701.4, U701.9 (LHPOUT)
/CODEC/LIN: C707.1, J701.7, U701.20 (LLINEIN)
/CODEC/LOUT: C722.2, J701.8, U701.12 (LOUT)
/CODEC/MICBIAS: J701.5, U701.17 (MICBIAS)
/CODEC/MICIN: J701.3, U701.18 (MICIN)
/CODEC/RHPOUT: J701.6, U701.10 (RHPOUT)
/CODEC/RIN: C701.1, J701.9, U701.19 (RLINEIN)
/CODEC/ROUT: C714.2, J701.10, U701.13 (ROUT)
/CODEC/VMID: C705.1, C706.1, U701.16 (VMID)
/ESP-main/IO4: U701.22 (CSB); also elsewhere on the board
/ESP-main/IO12: U701.24 (SCLK); also elsewhere on the board
/ESP-main/IO13: U701.23 (SDIN); also elsewhere on the board
/ESP-main/IO25: U701.5 (DACLRC), U701.7 (ADCLRC); also elsewhere on the board
GND: C702.2, C703.2, C704.2, C705.2, C706.2, C708.2, C710.2, C711.2, C712.2, C713.2, C715.2, C716.1, C718.2, C719.2, C720.2, C721.2, J701.1, J701.2, J702.2, J702.3, J703.2, J703.3, J704.3, J705.3, R704.1, R708.1, R712.2, R716.2, U701.11 (HPGND), U701.15 (AGND), U701.28 (DGND), U702.3 (+), U702.5 (+), U702.10 (+), U702.12 (+); also elsewhere on the board
unnamed: C701.2, C702.1, R703.1, R704.2
unnamed: C703.1, U701.25 (XTI/MCLK), Y701.1
unnamed: C704.1, U701.26 (XTO), Y701.2
unnamed: C707.2, C708.1, R707.1, R708.2
unnamed: C709.1, R709.2, R710.1, U702.9 (-)
unnamed: C709.2, R709.1, R711.2, U702.8
unnamed: C714.1, R710.2, R712.1
unnamed: C717.1, R713.2, R714.1, U702.13 (-)
unnamed: C717.2, R713.1, R715.2, U702.14
unnamed: C722.1, R714.2, R716.1
unnamed: J702.1, R702.2
unnamed: J703.1, R706.2
unnamed: J704.1, R711.1
unnamed: J705.1, R715.1
unnamed: R701.1, RV701.1
unnamed: R701.2, R702.1, U702.2 (-)
unnamed: R703.2, RV701.2, RV701.3, U702.1
unnamed: R705.1, RV701.4
unnamed: R705.2, R706.1, U702.6 (-)
unnamed: R707.2, RV701.5, RV701.6, U702.7

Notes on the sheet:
This section is pretty much taken from Mutable Instruments Clouds (c) Olivier Gillet
To external audio breakout. Useful for testing.

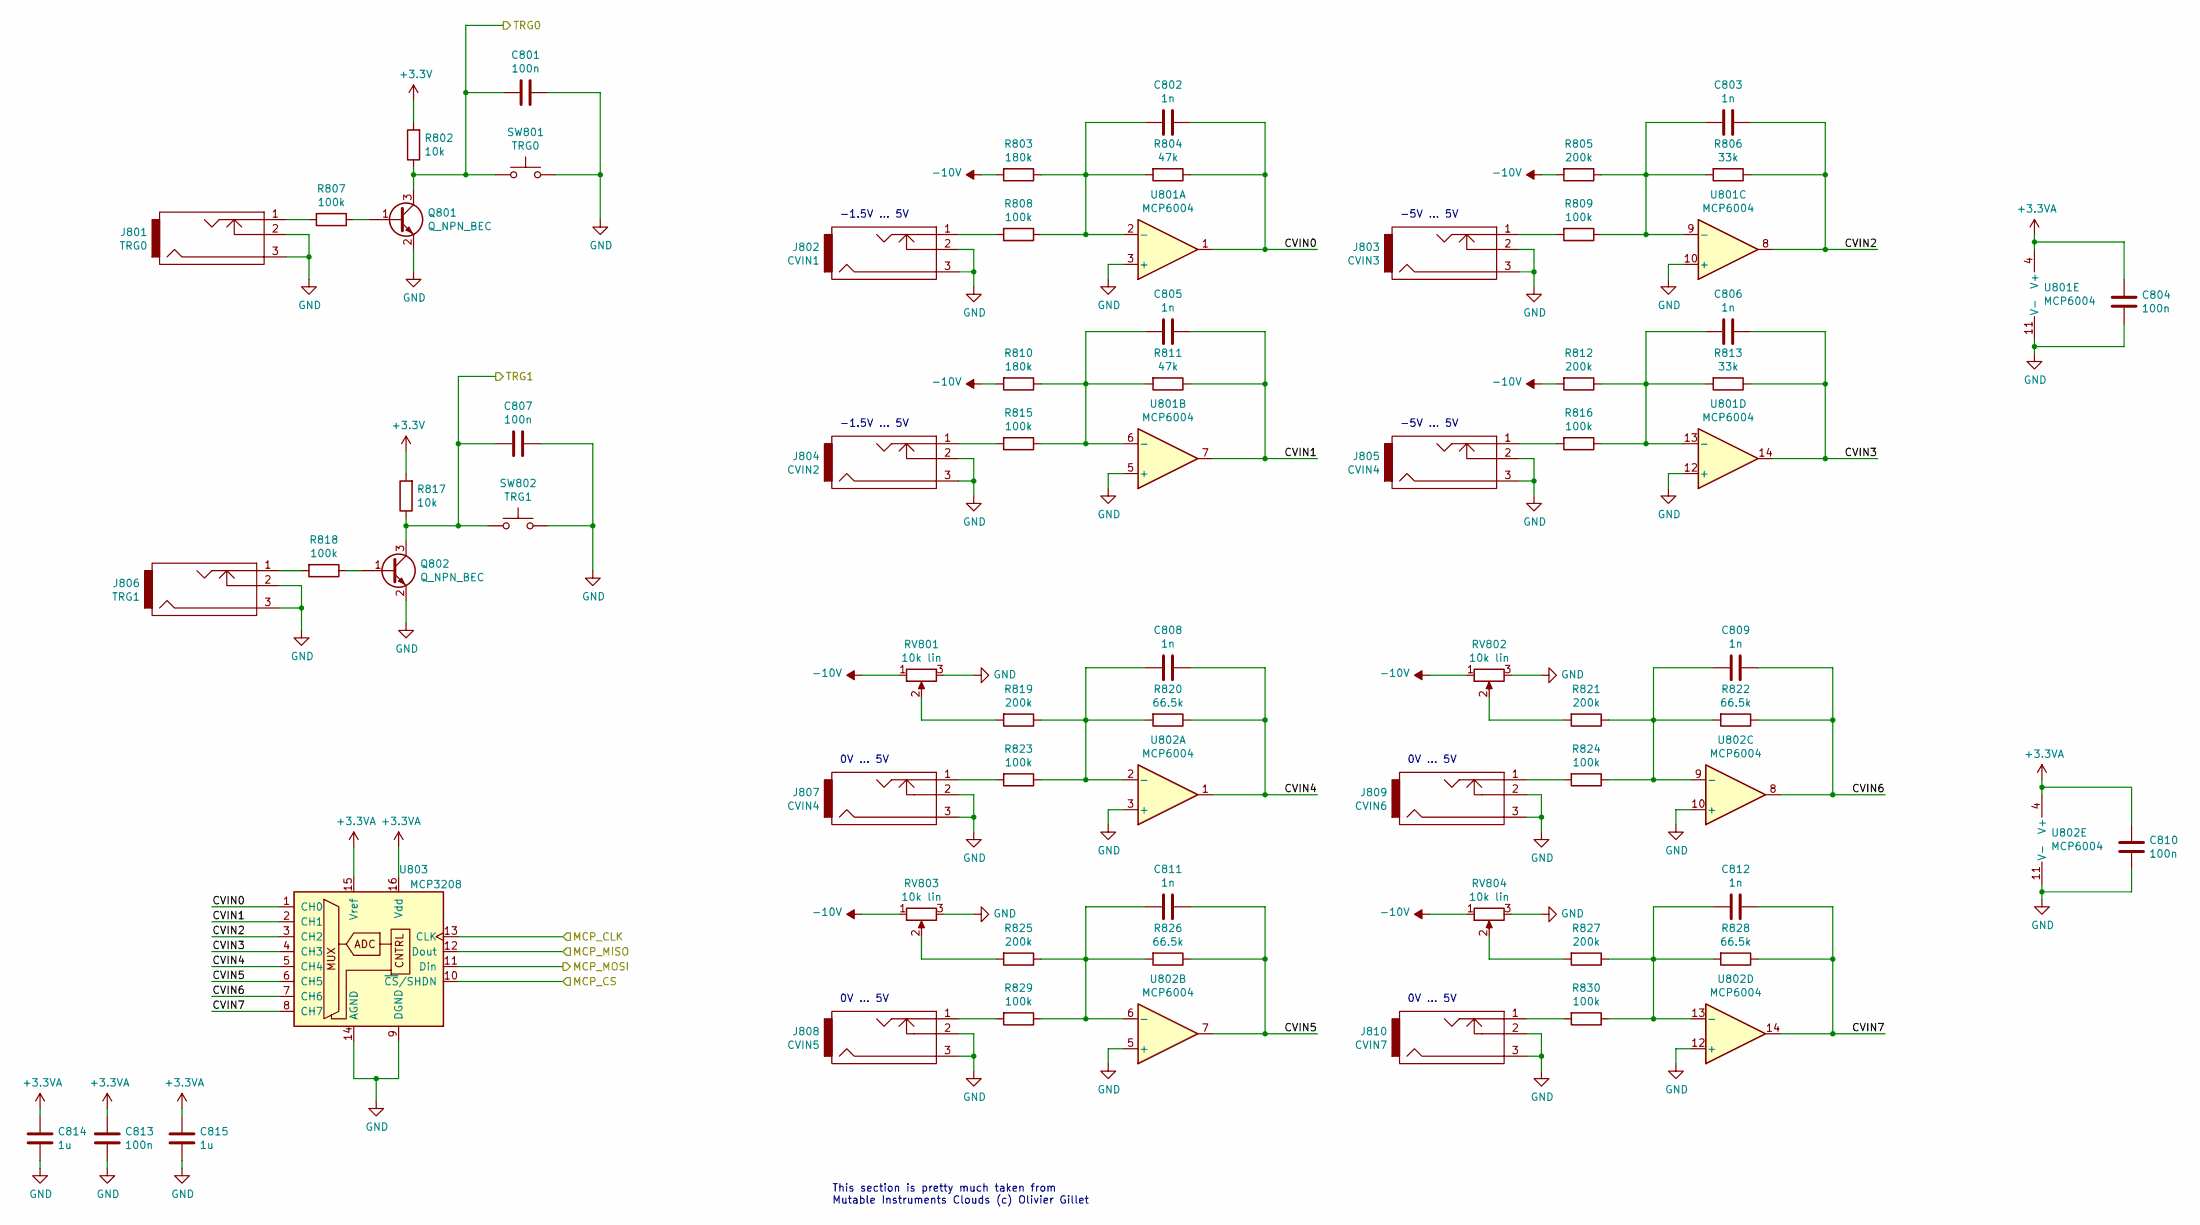
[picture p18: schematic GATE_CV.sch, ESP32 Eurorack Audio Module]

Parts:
C801, C804, C807, C810, C813: 100n; C_0603_1608Metric
C802, C803, C805, C806, C808, C809, C811, C812: 1n; C_0603_1608Metric
C814, C815: 1u; C_0603_1608Metric
J801: TRG0; THONKICONN
J802: CVIN1; THONKICONN
J803: CVIN3; THONKICONN
J804: CVIN2; THONKICONN
J805, J807: CVIN4; THONKICONN
J806: TRG1; THONKICONN
J808: CVIN5; THONKICONN
J809: CVIN6; THONKICONN
J810: CVIN7; THONKICONN
Q801, Q802: Q_NPN_BEC; SOT-23
R802, R817: 10k; R_0603_1608Metric
R803, R810: 180k; R_0603_1608Metric
R804, R811: 47k; R_0603_1608Metric
R805, R812, R819, R821, R825, R827: 200k; R_0603_1608Metric
R806, R813: 33k; R_0603_1608Metric
R807, R808, R809, R815, R816, R818, R823, R824, R829, R830: 100k; R_0603_1608Metric
R820, R822, R826, R828: 66.5k; R_0603_1608Metric
RV801, RV802, RV803, RV804: 10k lin; Alpha_9mm
SW801: TRG0; SW_6425
SW802: TRG1; SW_6425
U801, U802: MCP6004; TSSOP-14_4.4x5mm_P0.65mm
U803: MCP3208; SOIC-16_3.9x9.9mm_P1.27mm

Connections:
+3.3VA: C804.1, C810.1, C813.1, C814.1, C815.1, U801.4 (V+), U802.4 (V+), U803.15 (Vref), U803.16 (Vdd); also elsewhere on the board
-10V: R803.2, R805.2, R810.2, R812.2, RV801.1, RV802.1, RV803.1, RV804.1; also elsewhere on the board
/ESP-main/IO12: U803.13 (CLK); also elsewhere on the board
/ESP-main/IO13: U803.11 (Din); also elsewhere on the board
/ESP-main/IO32: U803.10 (~CS~/SHDN); also elsewhere on the board
/GATE_CV/CVIN0: C802.1, R804.1, U801.1, U803.1 (CH0)
/GATE_CV/CVIN1: C805.1, R811.1, U801.7, U803.2 (CH1)
/GATE_CV/CVIN2: C803.1, R806.1, U801.8, U803.3 (CH2)
/GATE_CV/CVIN3: C806.1, R813.1, U801.14, U803.4 (CH3)
/GATE_CV/CVIN4: C808.1, R820.1, U802.1, U803.5 (CH4)
/GATE_CV/CVIN5: C811.1, R826.1, U802.7, U803.6 (CH5)
/GATE_CV/CVIN6: C809.1, R822.1, U802.8, U803.7 (CH6)
/GATE_CV/CVIN7: C812.1, R828.1, U802.14, U803.8 (CH7)
/GATE_CV/TRG0: C801.2, Q801.3 (C), R802.1, SW801.1; also elsewhere on the board
/GATE_CV/TRG1: C807.2, Q802.3 (C), R817.1, SW802.1; also elsewhere on the board
/IO0: U803.12 (Dout); also elsewhere on the board
GND: C801.1, C804.2, C807.1, C810.2, C813.2, C814.2, C815.2, J801.2, J801.3, J802.2, J802.3, J803.2, J803.3, J804.2, J804.3, J805.2, J805.3, J806.2, J806.3, J807.2, J807.3, J808.2, J808.3, J809.2, J809.3, J810.2, J810.3, Q801.2 (E), Q802.2 (E), RV801.3, RV802.3, RV803.3, RV804.3, SW801.2, SW802.2, U801.3 (+), U801.5 (+), U801.10 (+), U801.11 (V-), U801.12 (+), U802.3 (+), U802.5 (+), U802.10 (+), U802.11 (V-), U802.12 (+), U803.9 (DGND), U803.14 (AGND); also elsewhere on the board
unnamed: C802.2, R803.1, R804.2, R808.1, U801.2 (-)
unnamed: C803.2, R805.1, R806.2, R809.1, U801.9 (-)
unnamed: C805.2, R810.1, R811.2, R815.1, U801.6 (-)
unnamed: C806.2, R812.1, R813.2, R816.1, U801.13 (-)
unnamed: C808.2, R819.1, R820.2, R823.1, U802.2 (-)
unnamed: C809.2, R821.1, R822.2, R824.1, U802.9 (-)
unnamed: C811.2, R825.1, R826.2, R829.1, U802.6 (-)
unnamed: C812.2, R827.1, R828.2, R830.1, U802.13 (-)
unnamed: J801.1, R807.2
unnamed: J802.1, R808.2
unnamed: J803.1, R809.2
unnamed: J804.1, R815.2
unnamed: J805.1, R816.2
unnamed: J806.1, R818.2
unnamed: J807.1, R823.2
unnamed: J808.1, R829.2
unnamed: J809.1, R824.2
unnamed: J810.1, R830.2
unnamed: Q801.1 (B), R807.1
unnamed: Q802.1 (B), R818.1
unnamed: R819.2, RV801.2
unnamed: R821.2, RV802.2
unnamed: R825.2, RV803.2
unnamed: R827.2, RV804.2

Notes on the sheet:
-1.5V ... 5V
-5V ... 5V
0V ... 5V
This section is pretty much taken from Mutable Instruments Clouds (c) Olivier Gillet

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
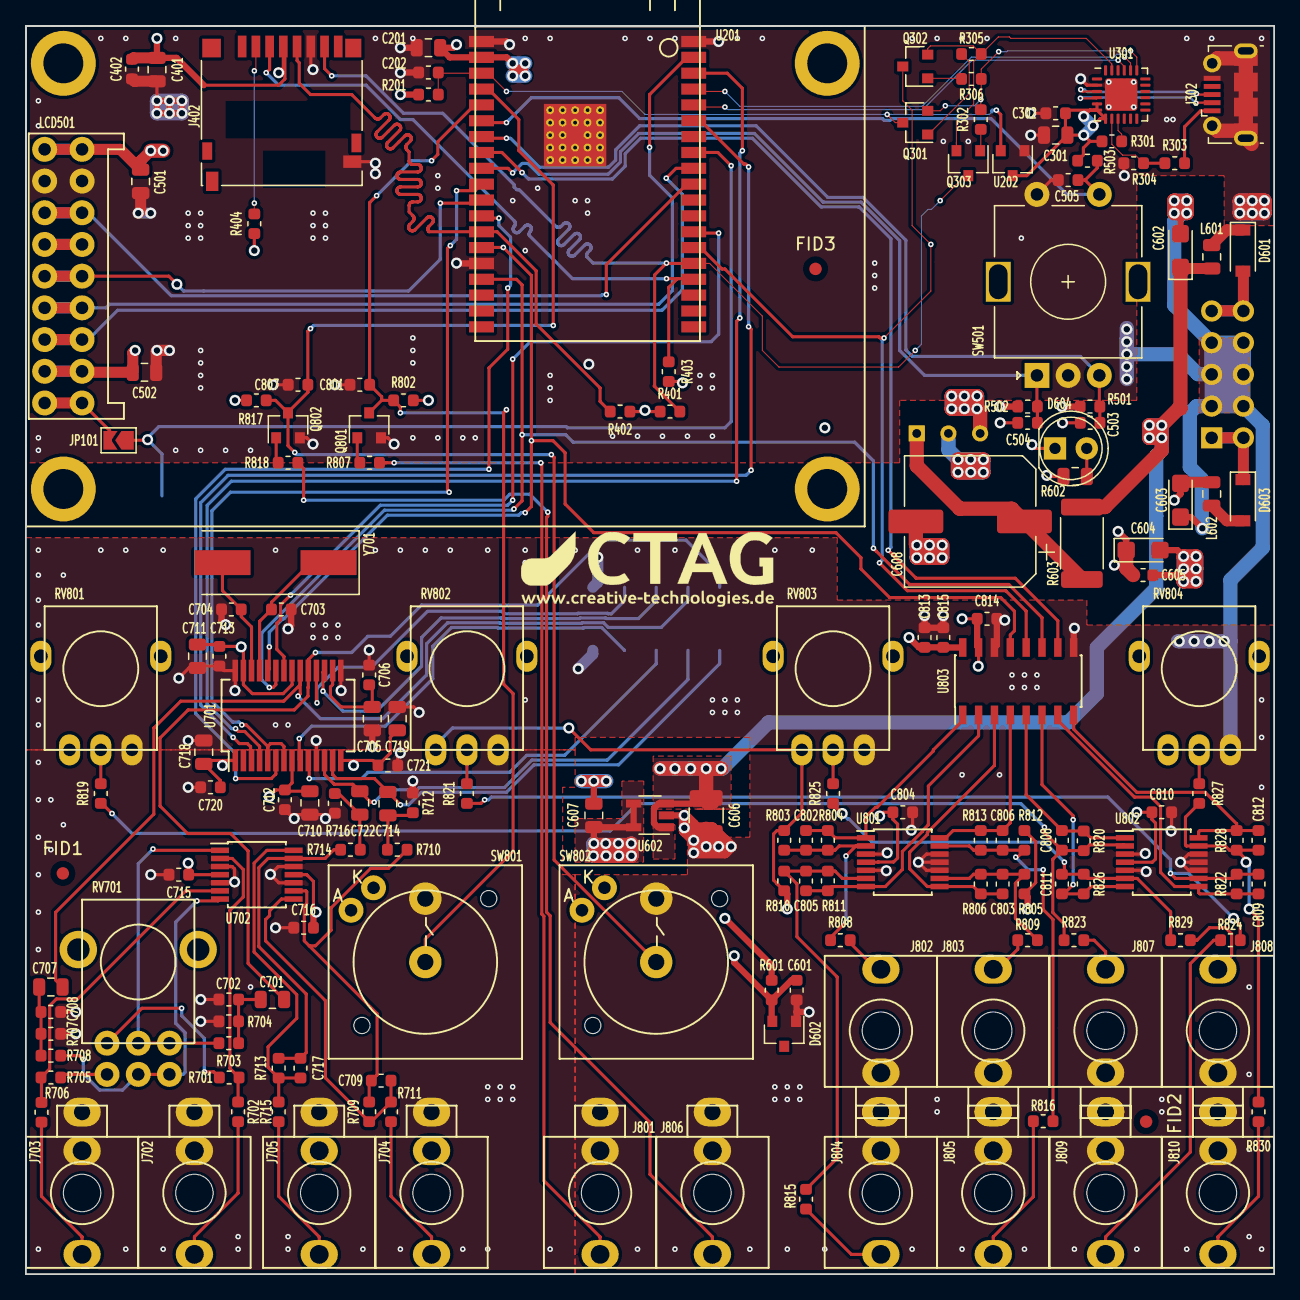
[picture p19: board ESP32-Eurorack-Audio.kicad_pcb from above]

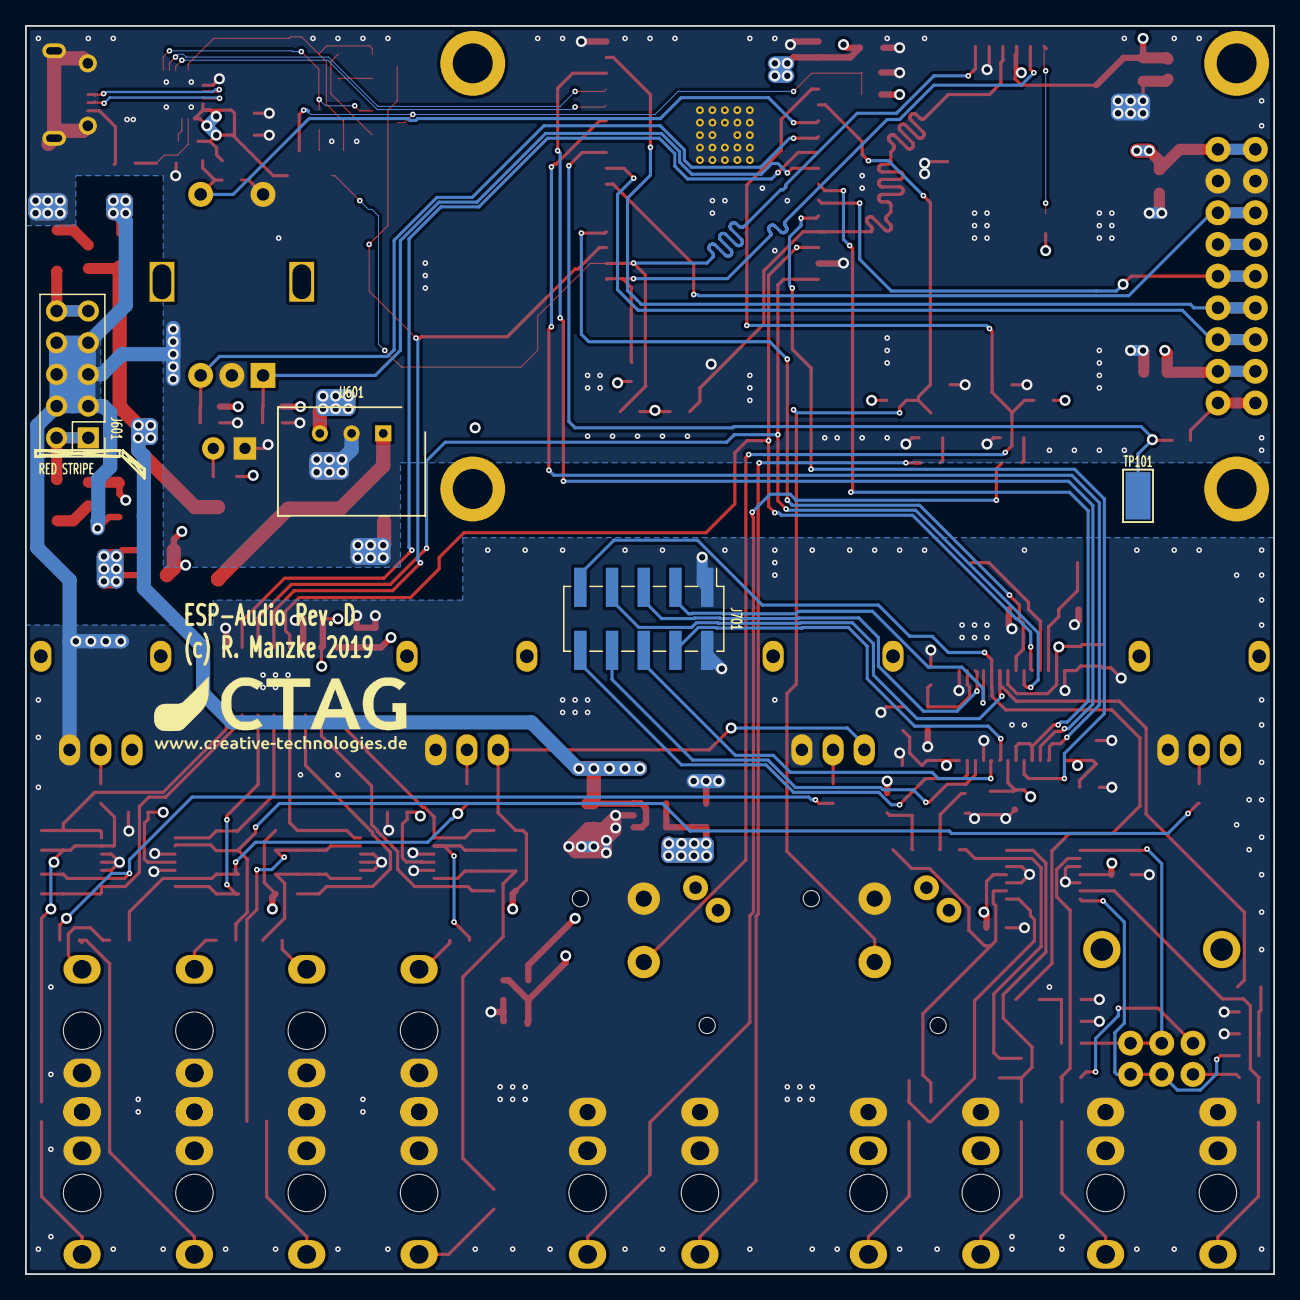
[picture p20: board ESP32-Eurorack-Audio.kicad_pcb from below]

Board: 4 copper layers, 100.0 x 100.0 mm, 171 parts (4 on the bottom side), 110 nets.

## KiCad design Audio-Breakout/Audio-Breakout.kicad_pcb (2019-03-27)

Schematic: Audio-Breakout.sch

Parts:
C1, C4, C5, C7, C9: 1u; C_0603_1608Metric
C2, C3: 220u; CP_Elec_10x10.5
C6, C8, C10: 220p; C_0603_1608Metric
FID1, FID2, FID3: Fiducial_1mm_Dia_2.54mm_Outer_CopperTop
J1: LINEOUT; PJ-301CM
J2: HPOUT; PJ-301CM
J3: AUEXT; PinHeader_2x05_P2.54mm_Vertical
J4: LINEIN; PJ-301CM
J5: MICIN; THONKICONN
R1, R4: 100; R_0603_1608Metric
R2, R3, R5, R6, R11: 47k; R_0603_1608Metric
R7, R9, R12, R13: 5k6; R_0603_1608Metric
R8: 680; R_0603_1608Metric
R10: RMIC; R_0603_1608Metric

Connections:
/LHPOUT: C2.1, J3.4
/LIN: C5.1, J3.7
/LOUT: C1.2, J3.8
/MICBIAS: J3.5, R8.1
/MICIN: J3.3, R10.1
/RHPOUT: C3.1, J3.6
/RIN: C9.1, J3.9
/ROUT: C4.2, J3.10
GND: C6.1, C8.1, C10.1, J1.S, J2.S, J3.1, J3.2, J4.S, J5.2, J5.3, R2.2, R3.2, R5.2, R6.2, R9.2, R11.2, R13.2
unnamed: C1.1, R1.2, R2.1
unnamed: C2.2, J2.T, R3.1
unnamed: C3.2, J2.R, R5.1
unnamed: C4.1, R4.2, R6.1
unnamed: C5.2, C6.2, R7.1, R9.1
unnamed: C7.1, R10.2
unnamed: C7.2, C8.2, J5.1, R8.2, R11.1
unnamed: C9.2, C10.2, R12.1, R13.1
unnamed: J1.R, R4.1
unnamed: J1.T, R1.1
unnamed: J4.R, R12.2
unnamed: J4.T, R7.2

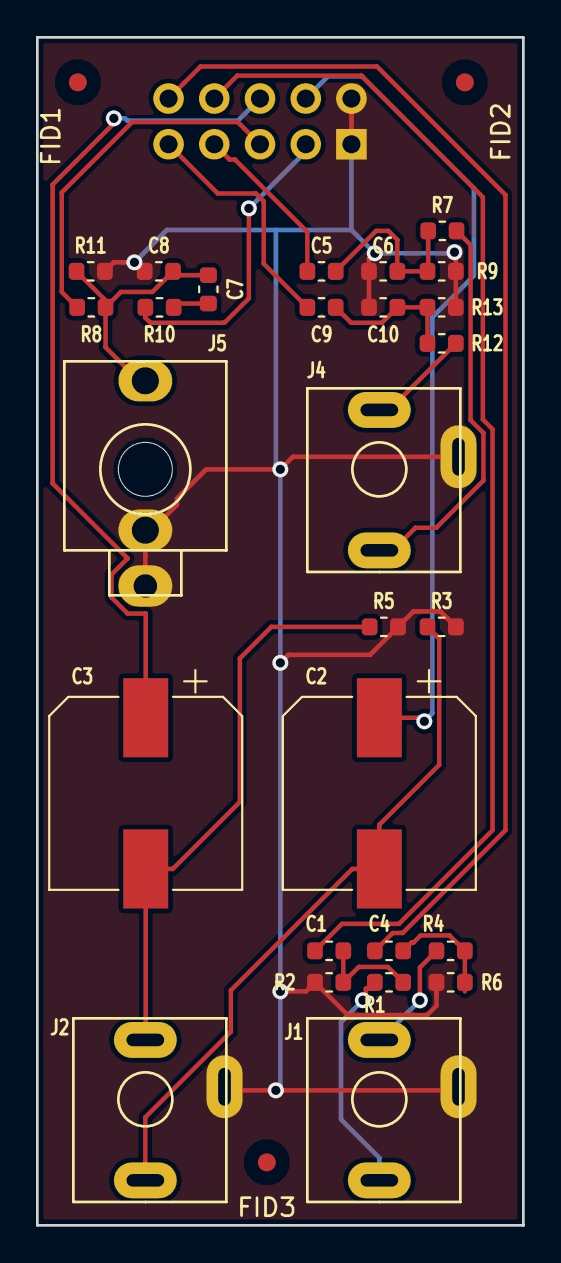
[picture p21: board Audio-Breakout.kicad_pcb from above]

Board: 2 copper layers, 27.0 x 66.0 mm, 31 parts (1 on the bottom side), 21 nets.

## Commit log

2019-03-27 libs added
    [CODEC.sch, ESP-main.sch, ESP32-Eurorack-Audio.sch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]
2019-04-27 updated files
    [ESP32-Eurorack-Audio-BOM-RevB2.xlsx, ESP32-Eurorack-Audio-BOM-RevC.xlsx]
2019-05-03 added frontplate design file
    [frontplate.kicad_pcb]
2019-05-13 cleaned up schematic
    [CODEC.sch, ESP-main.sch, ESP32-Eurorack-Audio.sch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]
2019-05-13 PCB and BOM updated, cleanups
    [ESP32-Eurorack-Audio-BOM-RevC.xlsx, ESP32-Eurorack-Audio-BOM-RevD.xlsx, ESP32-Eurorack-Audio.kicad_pcb]
2019-05-15 more frontplate design
    [frontplate-ctag.kicad_pcb, frontplate-iot.kicad_pcb]
2019-05-15 cleanups and gerbers
    [ESP32-Eurorack-Audio-B_Cu.gbl, ESP32-Eurorack-Audio-B_Mask.gbs, ESP32-Eurorack-Audio-B_SilkS.gbo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]
2019-05-17 sending for production
    [ESP32-Eurorack-Audio-B_Cu.gbl, ESP32-Eurorack-Audio-B_Mask.gbs, ESP32-Eurorack-Audio-B_SilkS.gbo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]
2019-05-25 updated bom
    [ESP32-Eurorack-Audio-BOM-RevD.xlsx]
2019-06-04 BOM errors fixed
    [ESP32-Eurorack-Audio-BOM-RevD.xlsx]
2019-06-13 added pcb fiducials, updated date
    [CODEC.sch, ESP-main.sch, ESP32-Eurorack-Audio.kicad_pcb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]
2019-06-14 gerber files updated, silkscreen fixed
    [ESP32-Eurorack-Audio-B_Cu.gbl, ESP32-Eurorack-Audio-B_Mask.gbs, ESP32-Eurorack-Audio-B_SilkS.gbo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]
